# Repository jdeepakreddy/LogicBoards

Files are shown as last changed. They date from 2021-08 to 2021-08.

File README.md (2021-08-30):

## Full Documentation

I will amend this documentation as the project progresses.

**Logic Board 1 Variants:**

- Logic Board 1A (WiFi + BLE 5.0)
	- LB1A_DCA7M4_R512MB_F4GB (Dual Core A7 + M4, 512MB DDR3L RAM, 4GB eMMC)
	- LB1A_SCA7M4_R512MB_F4GB (Single Core A7 + M4, 512MB DDR3L RAM, 4GB eMMC)
- Logic Board 1B (Only WiFi)
	- LB1B_DCA7M4_R512MB_F4GB (Dual Core A7 + M4, 512MB DDR3L RAM, 4GB eMMC)
	- LB1B_SCA7M4_R512MB_F4GB (Single Core A7 + M4, 512MB DDR3L RAM, 4GB eMMC)
- Logic Board 1C (Only BLE 5.0)
	- LB1C_DCA7M4_R512MB_F4GB (Dual Core A7 + M4, 512MB DDR3L RAM, 4GB eMMC)
	- LB1C_SCA7M4_R512MB_F4GB (Single Core A7 + M4, 512MB DDR3L RAM, 4GB eMMC)
- Logic Board 1D (No wireless)
	- LB1D_DCA7M4_R512MB_F4GB (Dual Core A7 + M4, 512MB DDR3L RAM, 4GB eMMC)
	- LB1D_SCA7M4_R512MB_F4GB (Single Core A7 + M4, 512MB DDR3L RAM, 4GB eMMC)

**Logic Board I/O:**

Common expansion Board for all Logic Board 1 Variants. 

## A little background about the project

How it all started.

### Problem

While I was working on couple of popular linux dev boards like the BeagleBone Black and the Raspberry Pi, I've faced a few bunch of problems with both of them. Ofcourse, they are both fantastic boards to work with and they both have good community support, but, I are missing few things:

- **Raspberry Pi Compute Module 4 + IO Board**
    - CM4 is easy to use but not ideal for mass production.
    - No support for analog signals at hardware level.
    - Software PWM possible but not very precise.
    - Cannot support real time application or processing.
    - Not fully open-source and very minimum customization possible. <br>
<br>

- **BeagleBone Black**
    - Easy to use but user has to own build hardware for production.
    - PRUs make RT applications possible but super difficult to use.
    - Cannot support MIPI-DSI and HD graphics.
    - Programming PRUs is not an easy task.

### Solution

**Best of both worlds**

**Hello World STM32MP1 !!**

- Board design inspired from Raspberry Pi Compute Module 4 and CM4 IO board.
- Operating system derived from Beaglebone Black with implementation of Bonescript Library and Cloud9 IDE.
- Footprint compatible Single or dual Cortex-A7 Processors + dedicated Cortex-M4 core for real-time and low-power applications.
- Support for MIPI-DSI display for HMI applications.
- Fully open-source Hardware and Software.

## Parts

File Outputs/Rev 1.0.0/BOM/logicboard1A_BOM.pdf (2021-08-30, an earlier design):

Date | 28/07/2021
Rev. No. | 1.0.0
S/N | REF DESIGNATOR | MANUFACTURER PART NUMBER | VALUE | PACKAGE | QTY
1 | U8 | LBEE59B1LV-278 | - | | 1
2 | R49,R48,R47 | ERJ-1GN0R00C | 0E | 0201 | 3
3 | L8,L7 | LQP03TG1N5C02D | 1.5nH | 0201 | 2
4 | L6 | LQP03TG3N0C02D | 3.0nH | 0201 | 1
5 | L5 | LQP03TG1N0C02D | 1.0nH | 0201 | 1
6 | C86,C79,C32,C4,C40,C39,C38,C37,C36,C31,C30,C2 9,C28,C27,C26,C25,C24,C23,C20,C19,C18,C17,C16, C15,C14,C13,C12,C11,C10,C9,C8,C3 | 04026D104KAT2A | 100nF | 0402 | 32
7 | C85,C62,C61,C60,C59,C58,C57,C56,C55,C53 | GRM155R61A475MEAAD | 4.7uF | 0402 | 10
8 | C78 | GRT0335C1H2R0CA02D | 2.0pF | 0201 | 1
9 | C71,C33 | GRT0335C1ER30WA02D | 0.3pF | 0201 | 2
10 | U1 | STM32MP157CAC3 | - | | 1
11 | U2 | AS4C256M16D3LC-12BCN | - | | 1
12 | R6,R46,R35,R27 | RC0402JR-1010KL | 10k | 0402 | 4
13 | U7,U6,U5 | DF40C-70DP-0.4V(51) | - | | 3
14 | C76,C77,C75 | 04026A100KAT2A | 10pF | 0402 | 3
15 | C74,C73,C72,C70,C69,C68,C67,C66,C65,C64,C63,C 52,C51,C6,C5,C2,C1 | JMK105BJ105KV-F | 1uF | 0402 | 17
16 | X2 | TSX-3225 24.0000MF10Z-C3 | 24MHz | | 1
17 | X1 | SIT1533AC-H5-DCC-32.768E | 32.768kHz | | 1
18 | U4 | STPMIC1BPQR | - | | 1
19 | U3 | S40FC004C1B2C00000 | - | | 1
20 | R45,R44,R43,R42,R41,R40,R39,R38,R37,R36 | RC0402FR-0747KL | 47k | 0402 | 10
21 | R34,R1 | RC0402JR-07240RL | 240E | 0402 | 2
22 | R33,R32,R31,R30,R29,R28,R25,R24,R23,R22,R21,R 20,R19,R18,R17,R16,R15,R14,R13,R12,R11,R10,R9, R8 | RC0402JR-0756RL | 56E | 0402 | 24
23 | R26 | RC0402JR-7D100RL | 100E | 0402 | 1
24 | R7 | RC0402FR-073KL | 3k | 0402 | 1
25 | R5,R4,R3,R2 | RC0402FR-7D1K5L | 1k5 | 0402 | 4

LOGIC BOARD 1A BILL OF MATERIALS www.logicboards.org

26 | L4,L3,L2,L1 | MGV2520101R0M-10 | 1uH | 0402 | 4
27 | C54,C46,C45,C44,C43,C41,C35,C34,C22,C21 | GRM155R60J106ME15D | 10uF | 0402 | 10
28 | C50,C49,C48,C47 | C3216X5R1V226M160AC | 22uF | 1206 | 4
29 | C42 | LMK105ABJ225KVHF | 2.2uF | 0402 | 1
30 | C7 | GRM155R71H103KA88D | 10nF | 0402 | 1

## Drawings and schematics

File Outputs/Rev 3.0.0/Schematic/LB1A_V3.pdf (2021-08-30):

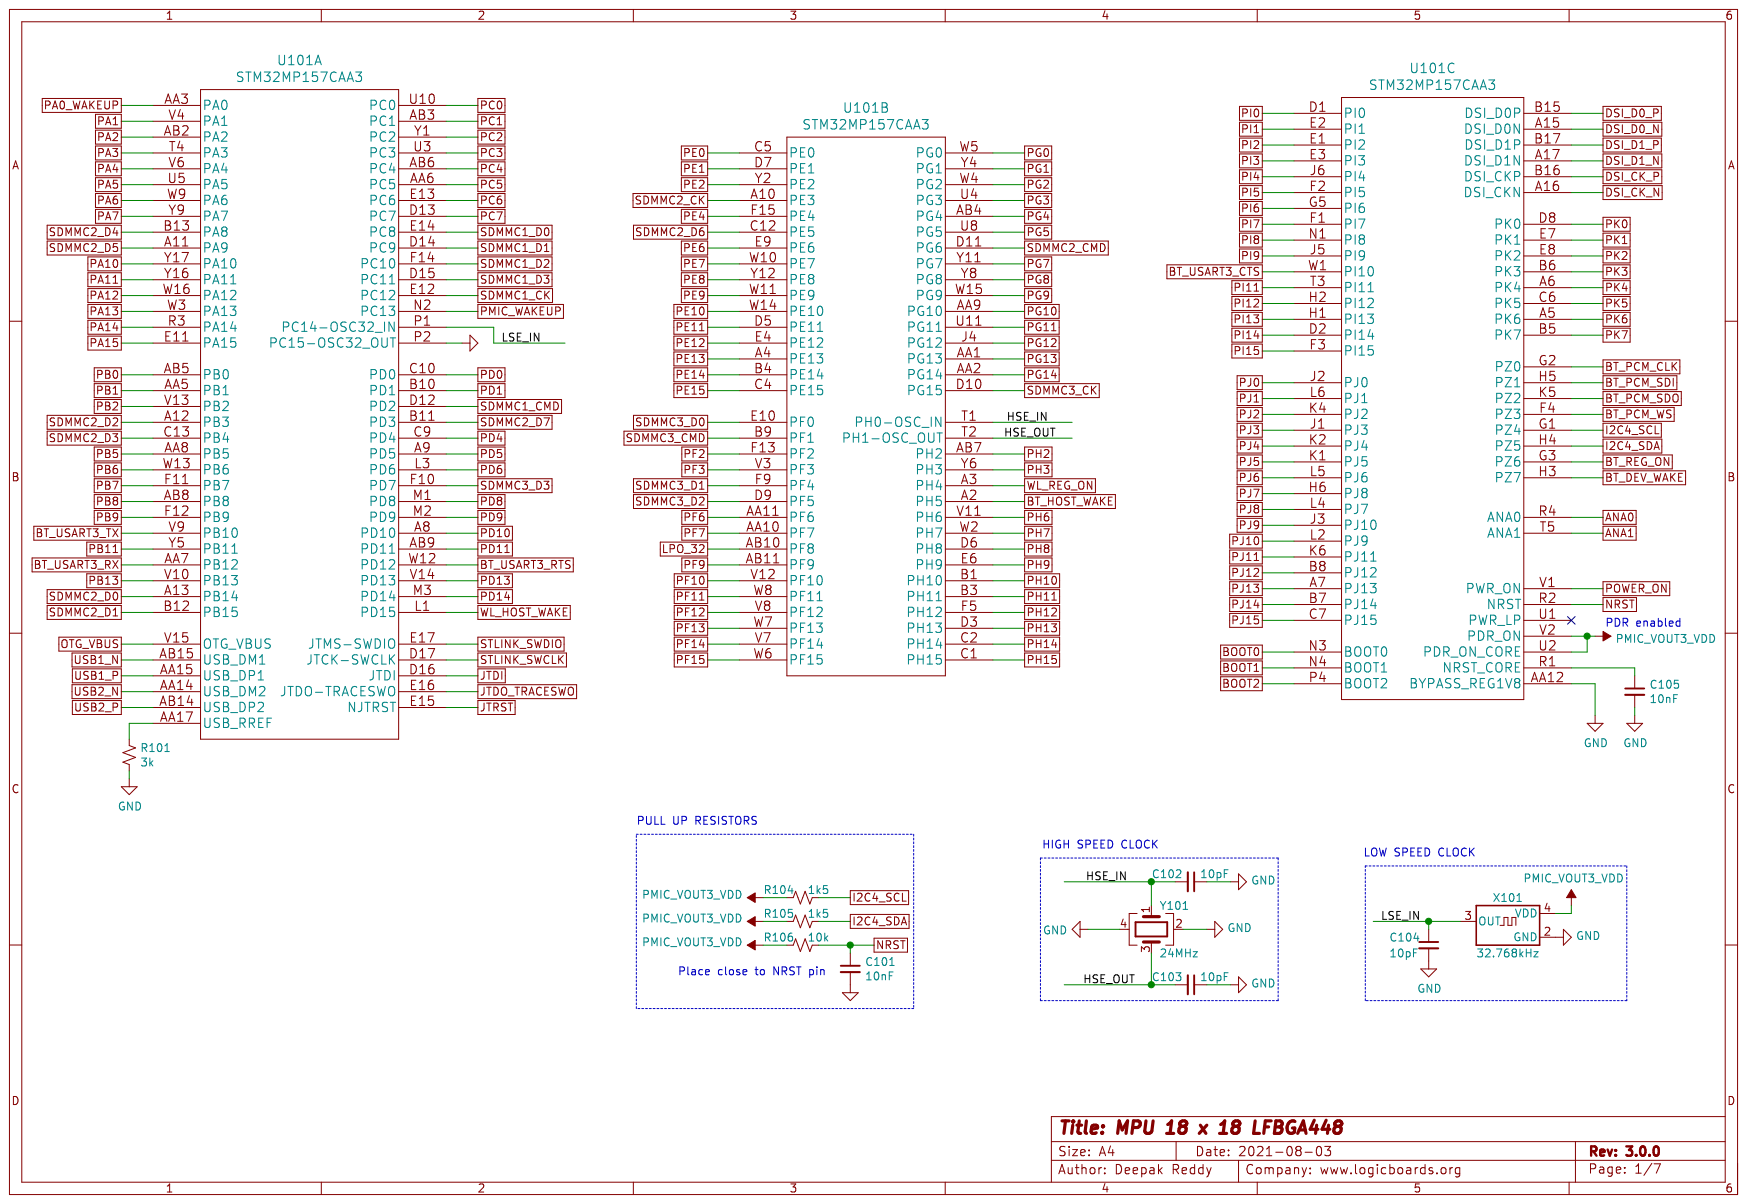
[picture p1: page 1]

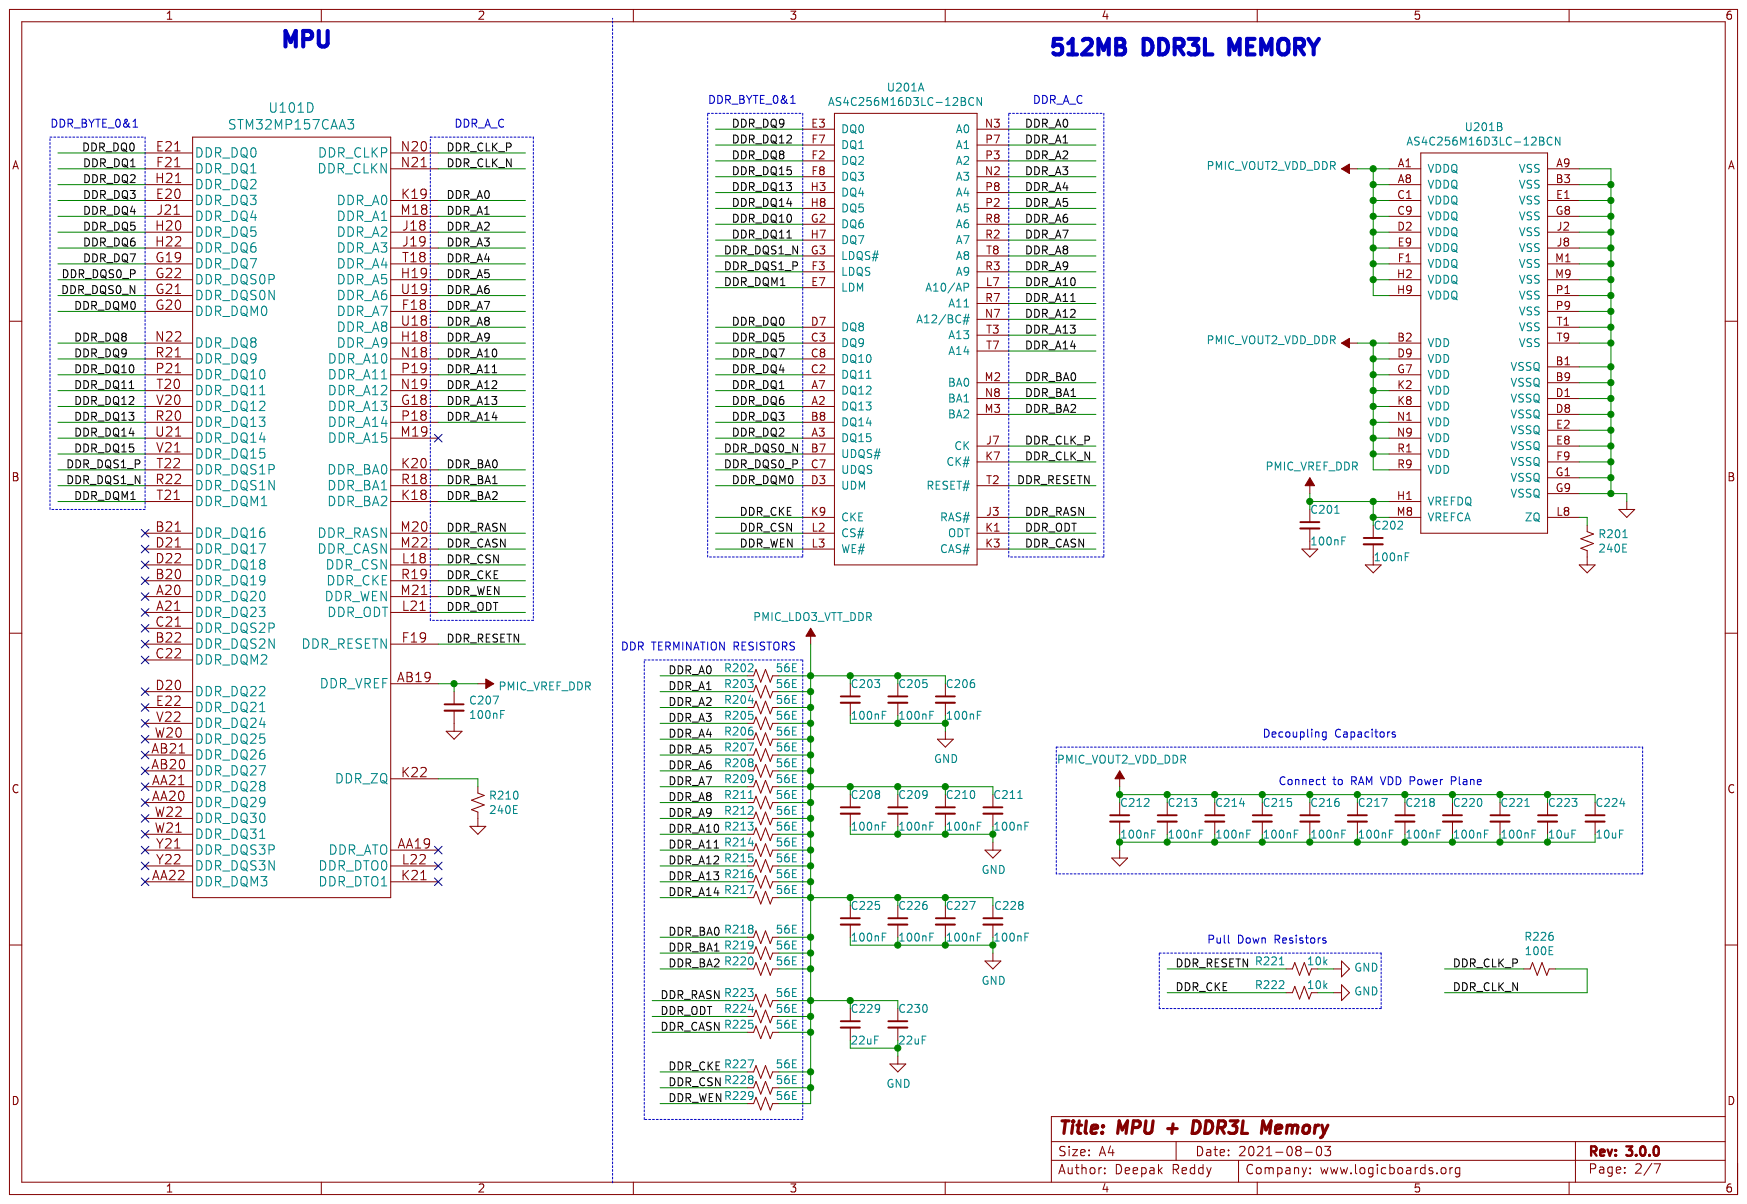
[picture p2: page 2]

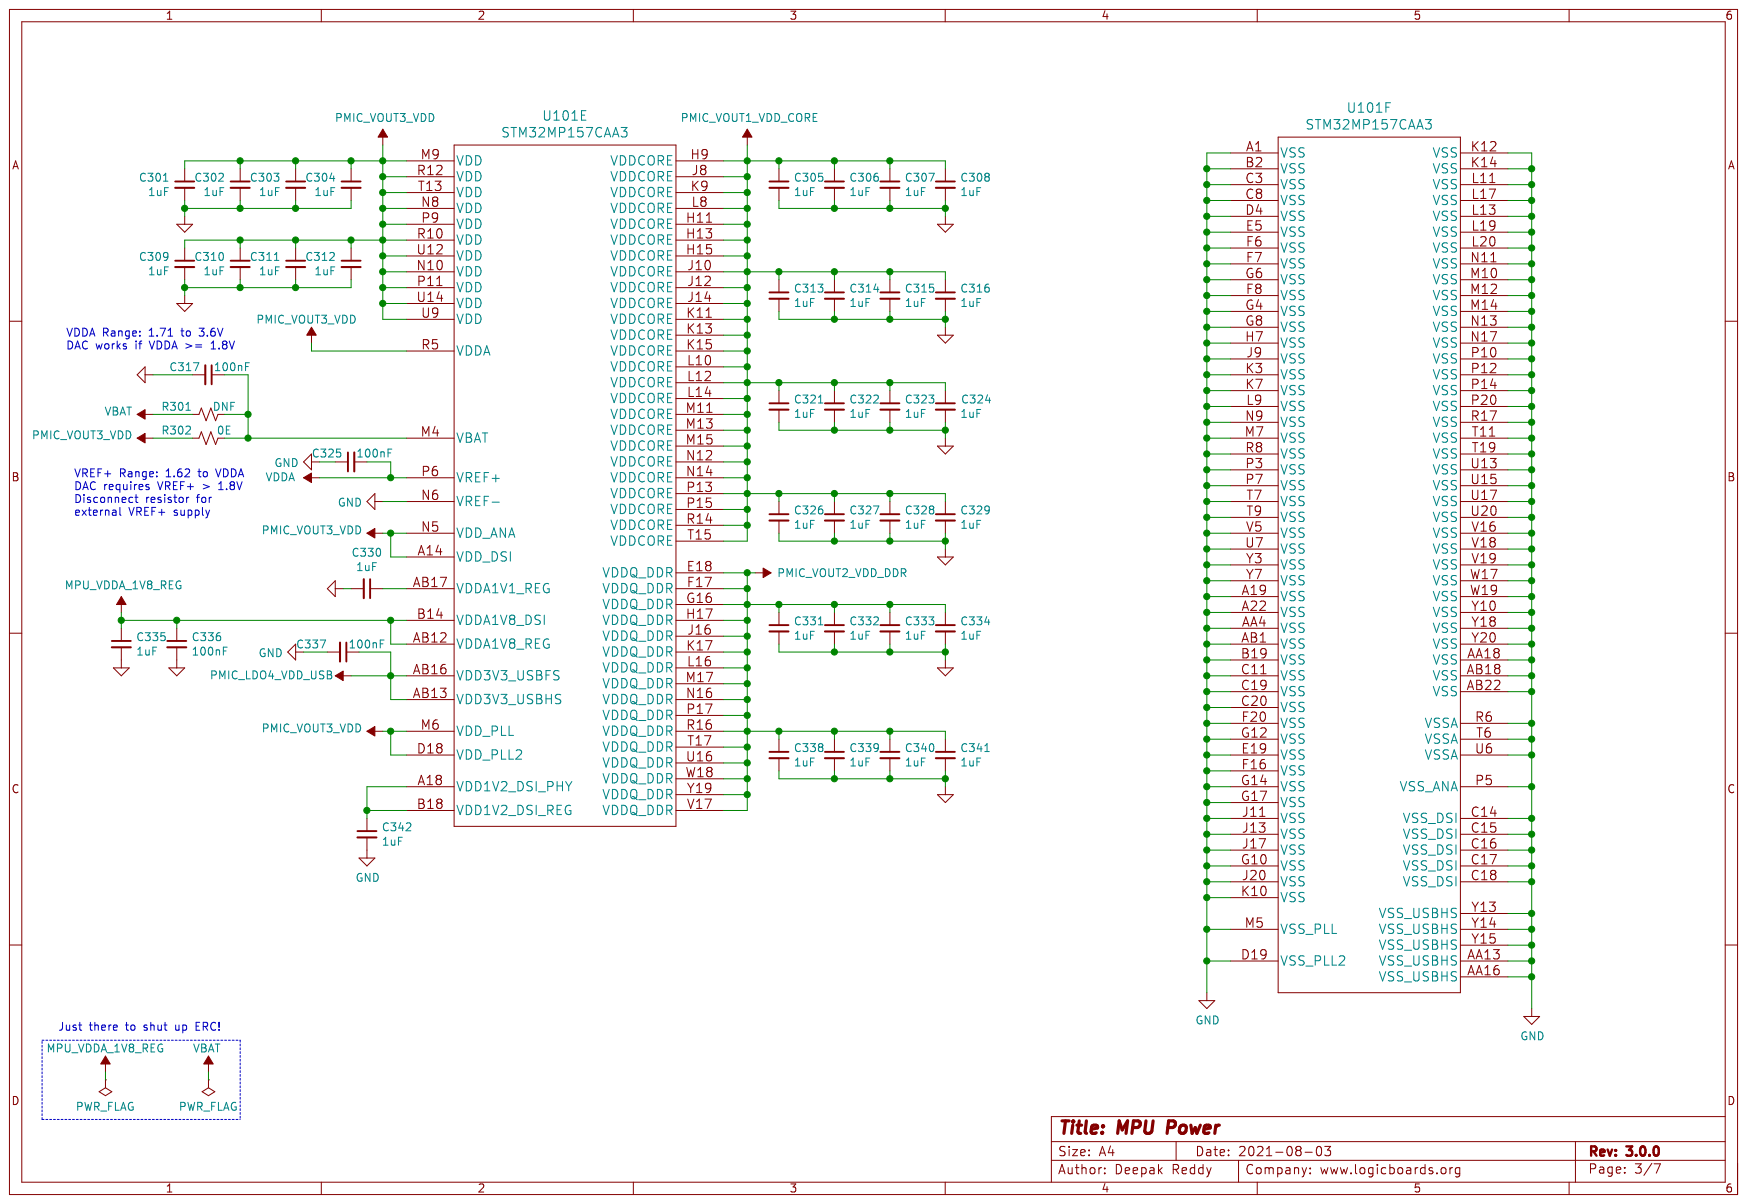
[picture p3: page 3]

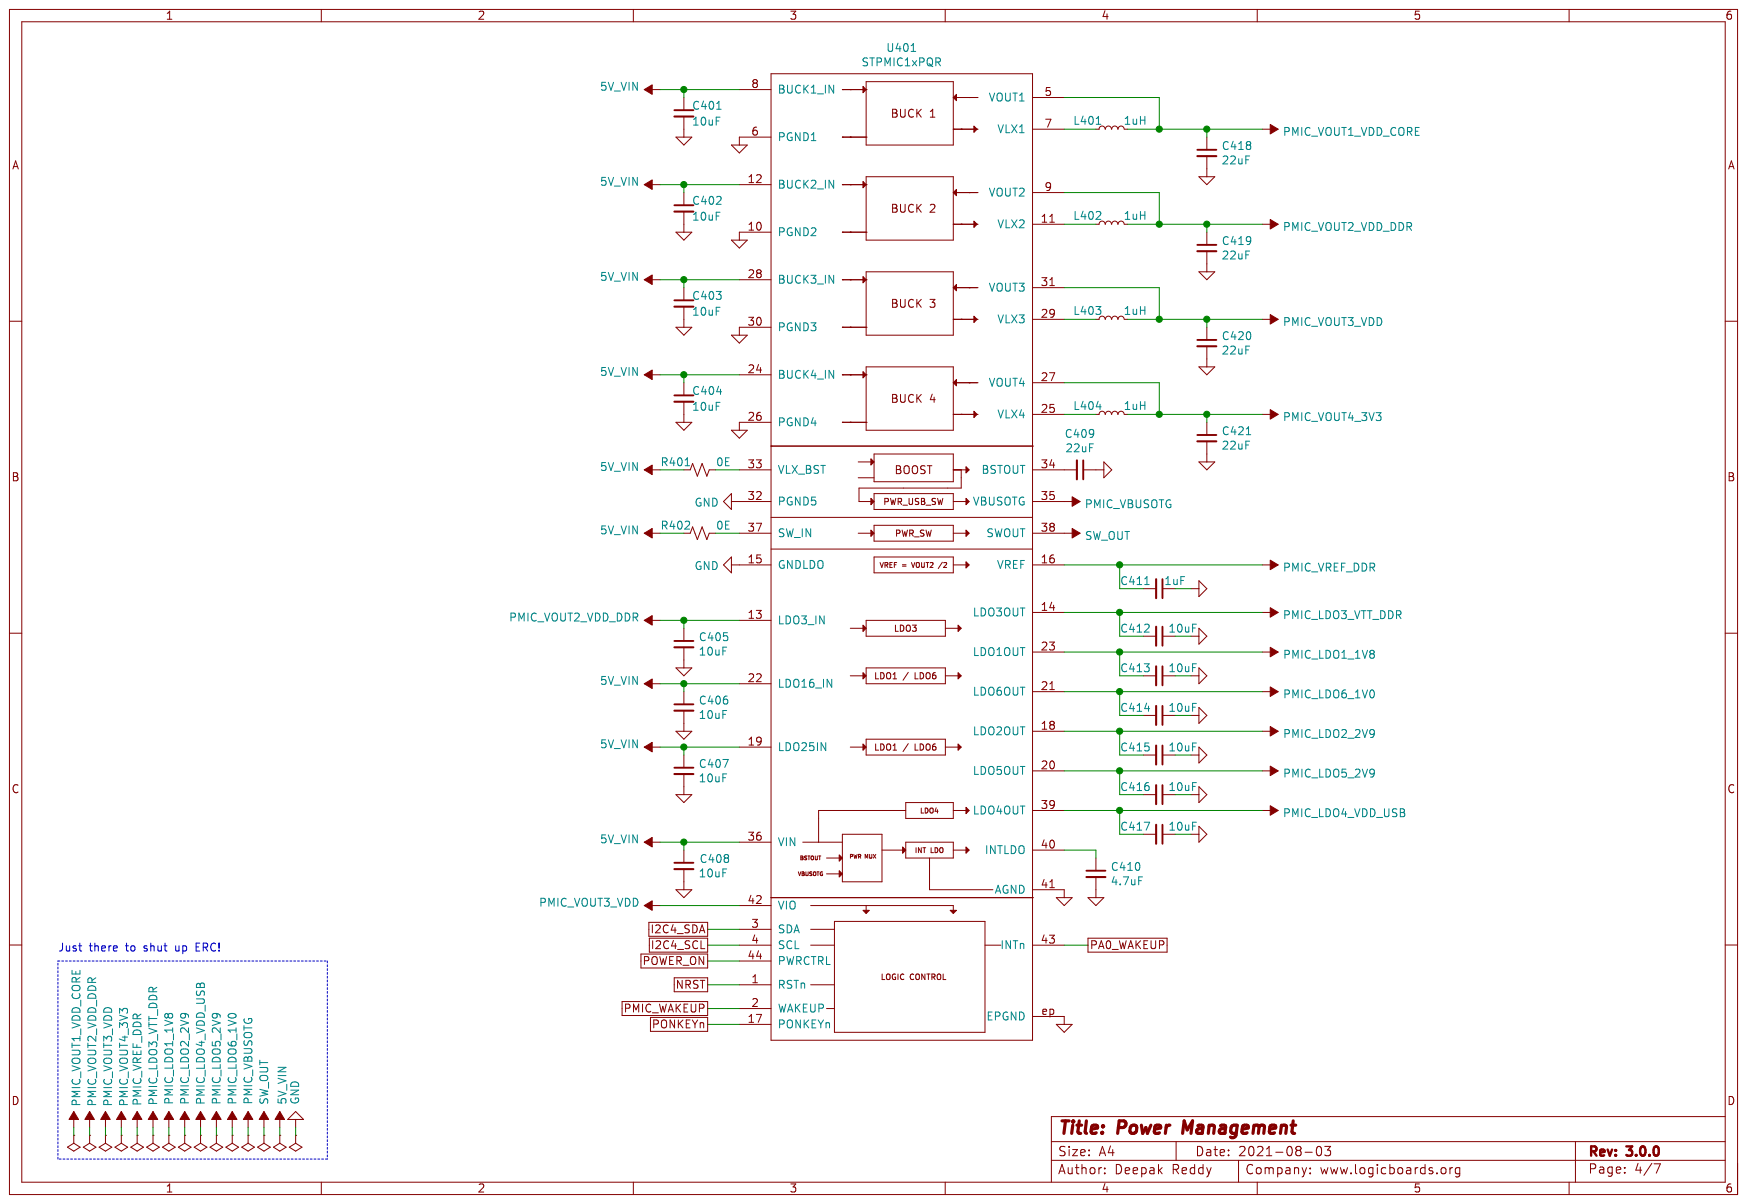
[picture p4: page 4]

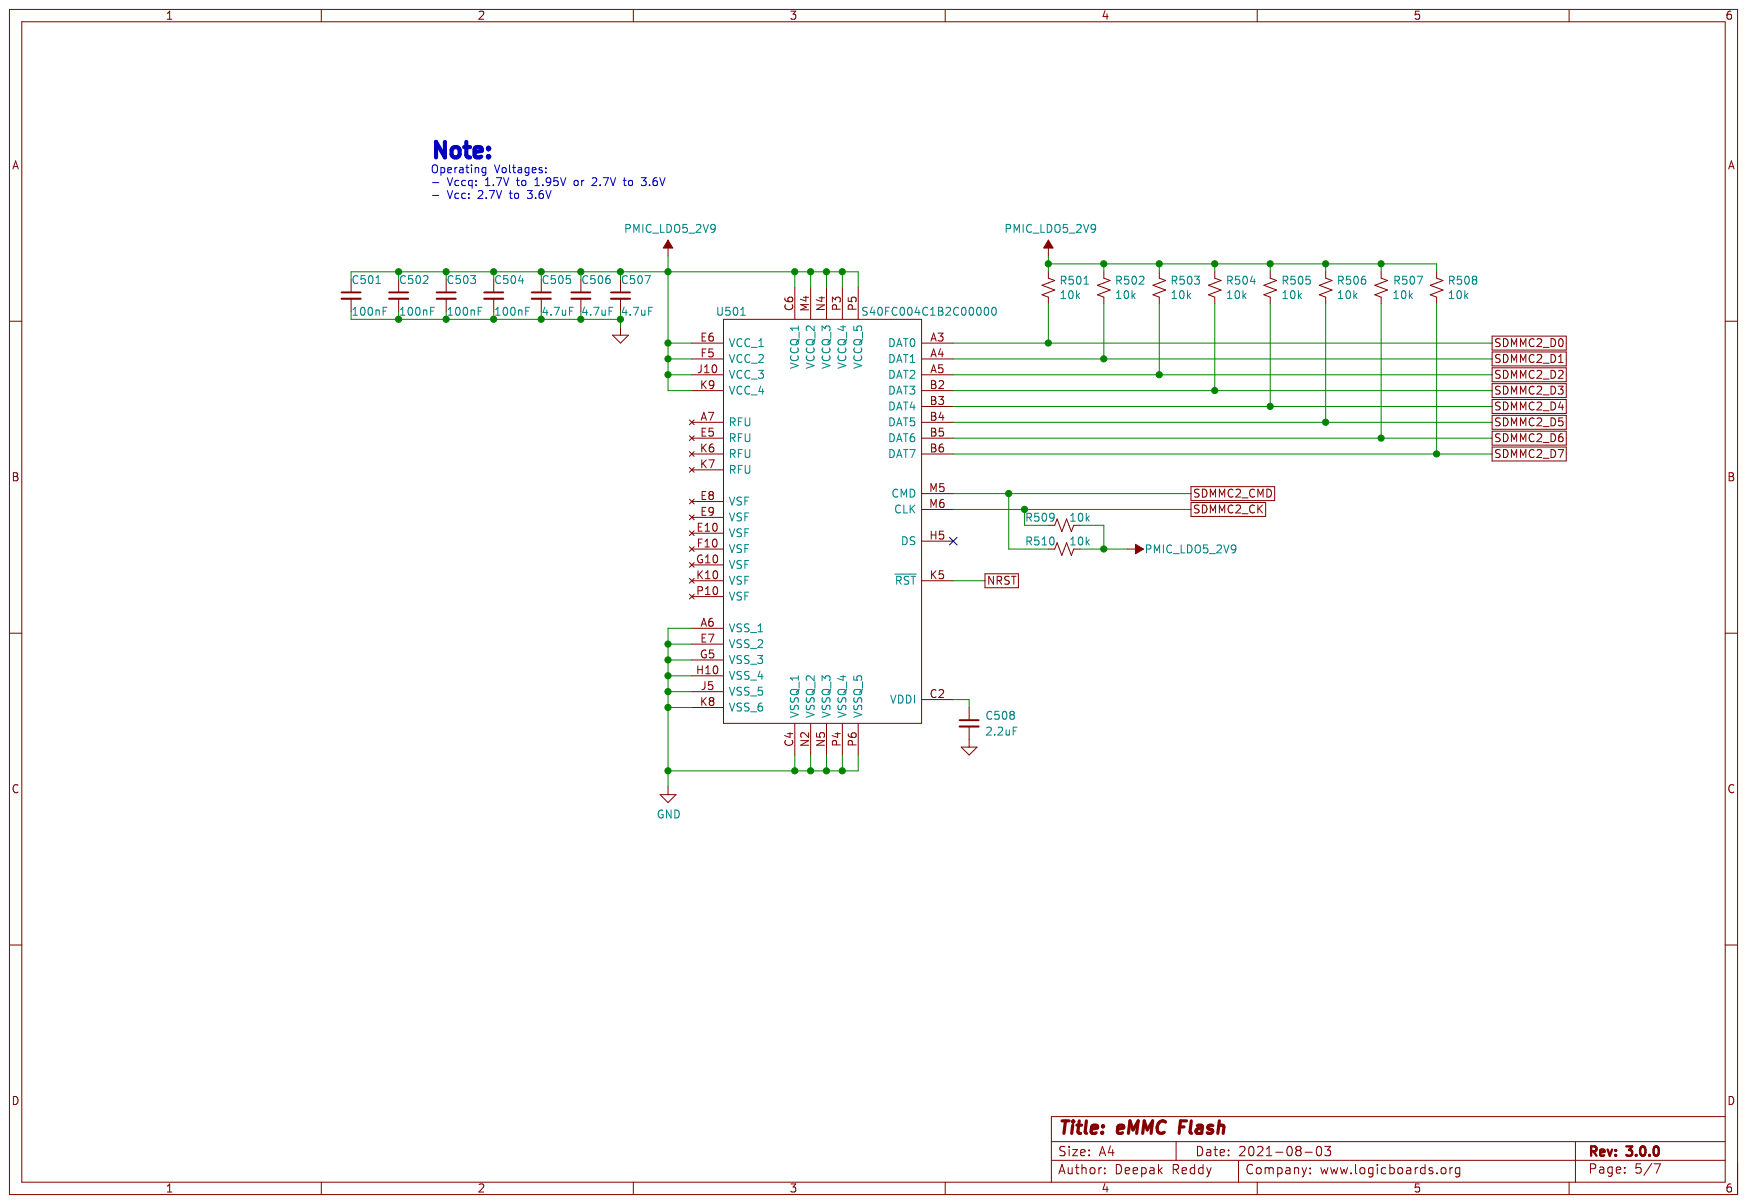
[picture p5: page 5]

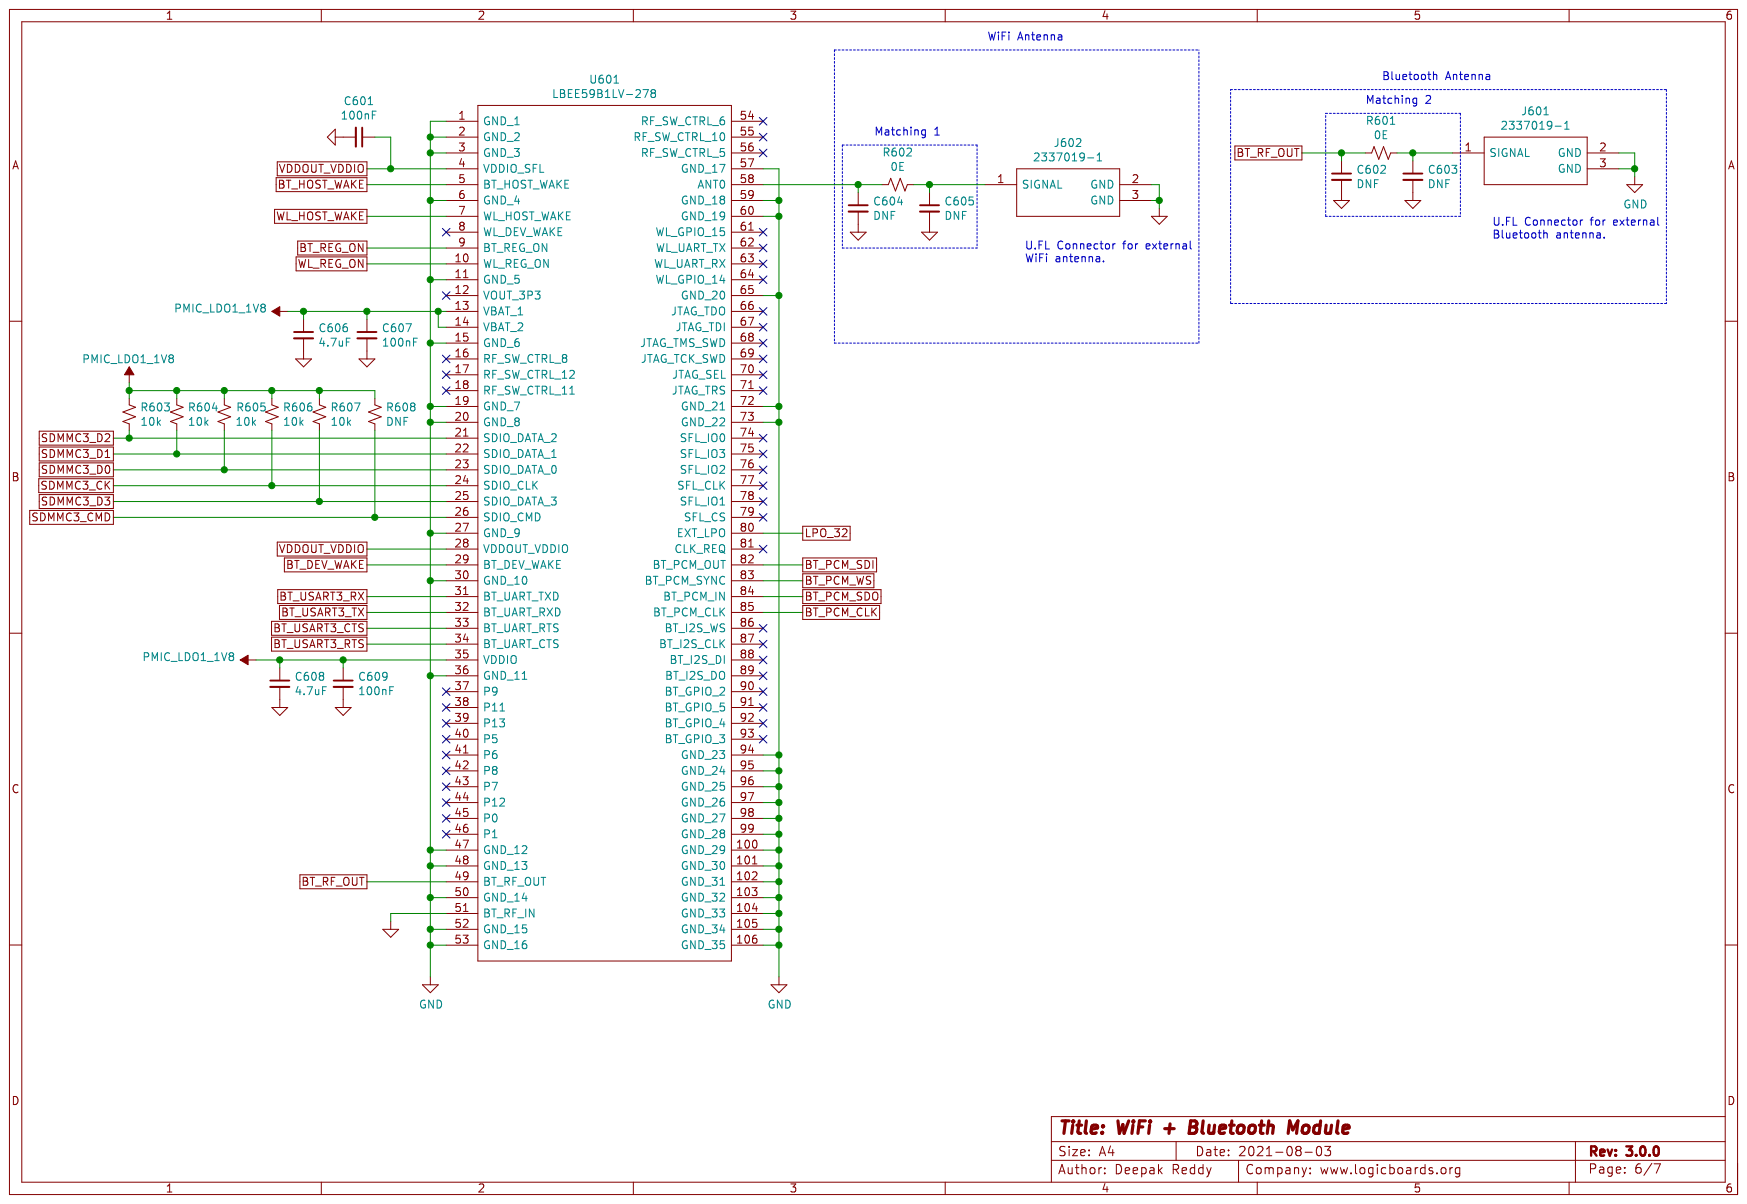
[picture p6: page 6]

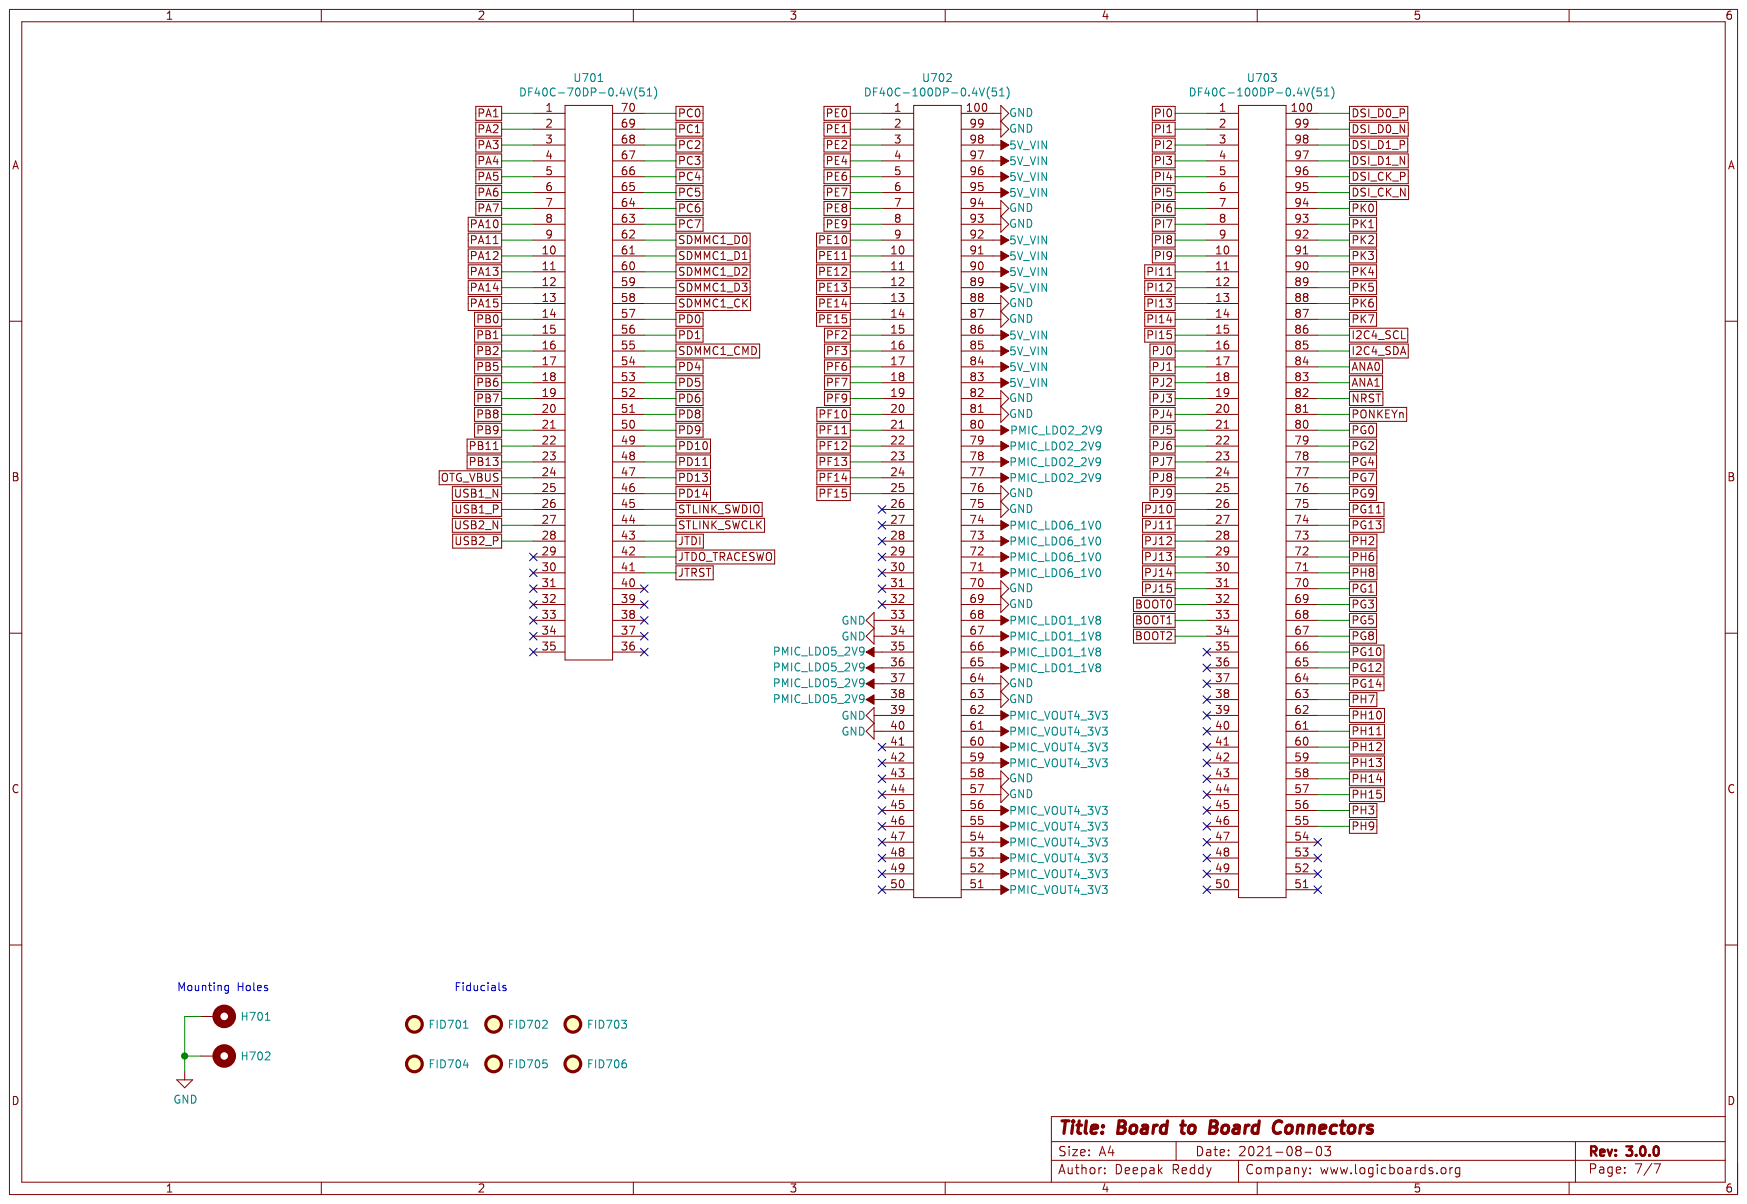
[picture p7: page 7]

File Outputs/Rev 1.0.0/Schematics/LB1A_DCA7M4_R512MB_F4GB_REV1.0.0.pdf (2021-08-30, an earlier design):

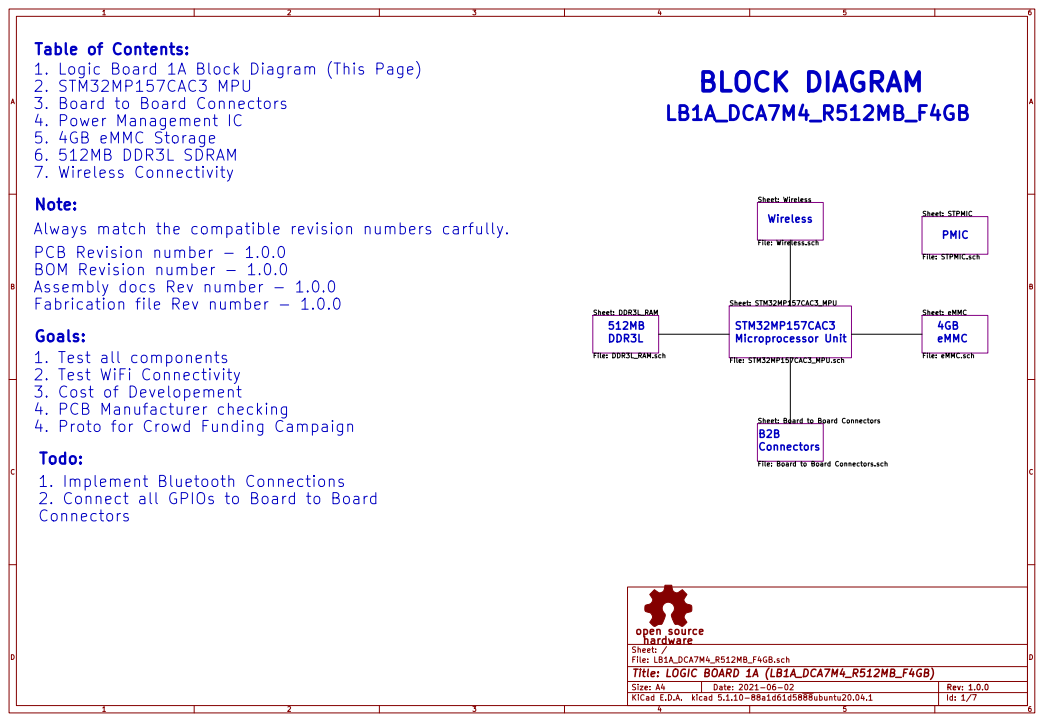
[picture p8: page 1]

Table of Contents:
1. Logic Board 1A Block Diagram (This Page)
2. STM32MP157CAC3 MPU
3. Board to Board Connectors
4. Power Management IC
5. 4GB eMMC Storage
6. 512MB DDR3L SDRAM
7. Wireless Connectivity
Note:
Always match the compatible revision numbers carfully.
PCB Revision number - 1.0.0
BOM Revision number - 1.0.0
Assembly docs Rev number - 1.0.0
Fabrication file Rev number - 1.0.0
Goals:
1. Test all components
2. Test WiFi Connectivity
3. Cost of Developement
4. PCB Manufacturer checking
4. Proto for Crowd Funding Campaign
Todo:
1. Implement Bluetooth Connections
2. Connect all GPIOs to Board to Board
Connectors

BLOCK DIAGRAM
LB1A_DCA7M4_R512MB_F4GB
Sheet: Wireless File: Wireless.sch Sheet: Board to Board Connectors File: Board to Board Connectors.sch Sheet: STM32MP157CAC3_MPU
File: DDR3L_RAM.sch hardware open source

File: STPMIC.sch Sheet: eMMC

File: LB1A_DCA7M4_R512MB_F4GB.sch Sheet: /
Id: 1/7 Title: LOGIC BOARD 1A (LB1A_DCA7M4_R512MB_F4GB)

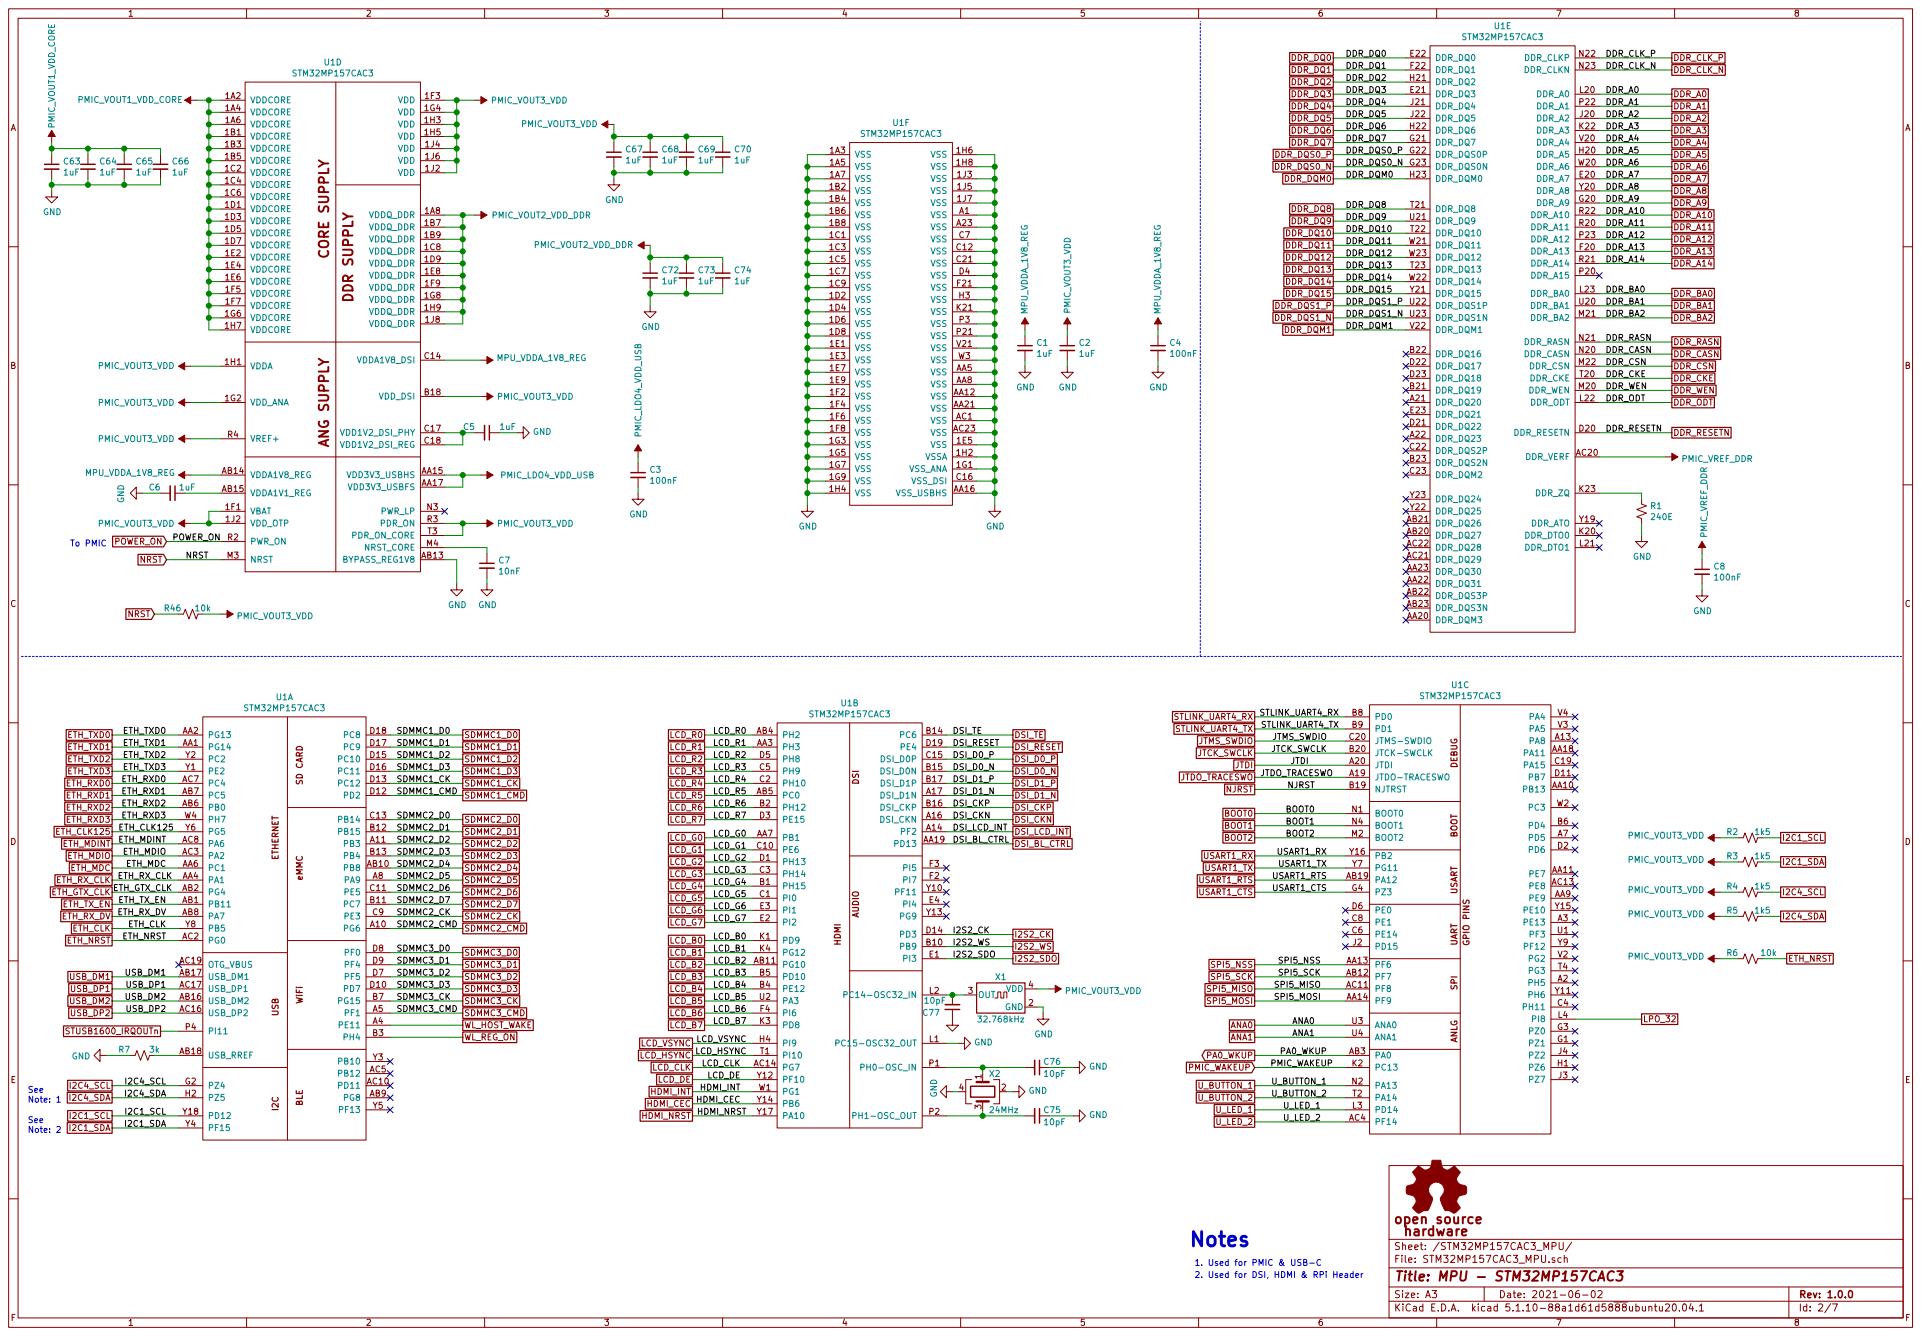
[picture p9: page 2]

1. Used for PMIC & USB-C
2. Used for DSI, HDMI & RPi Header

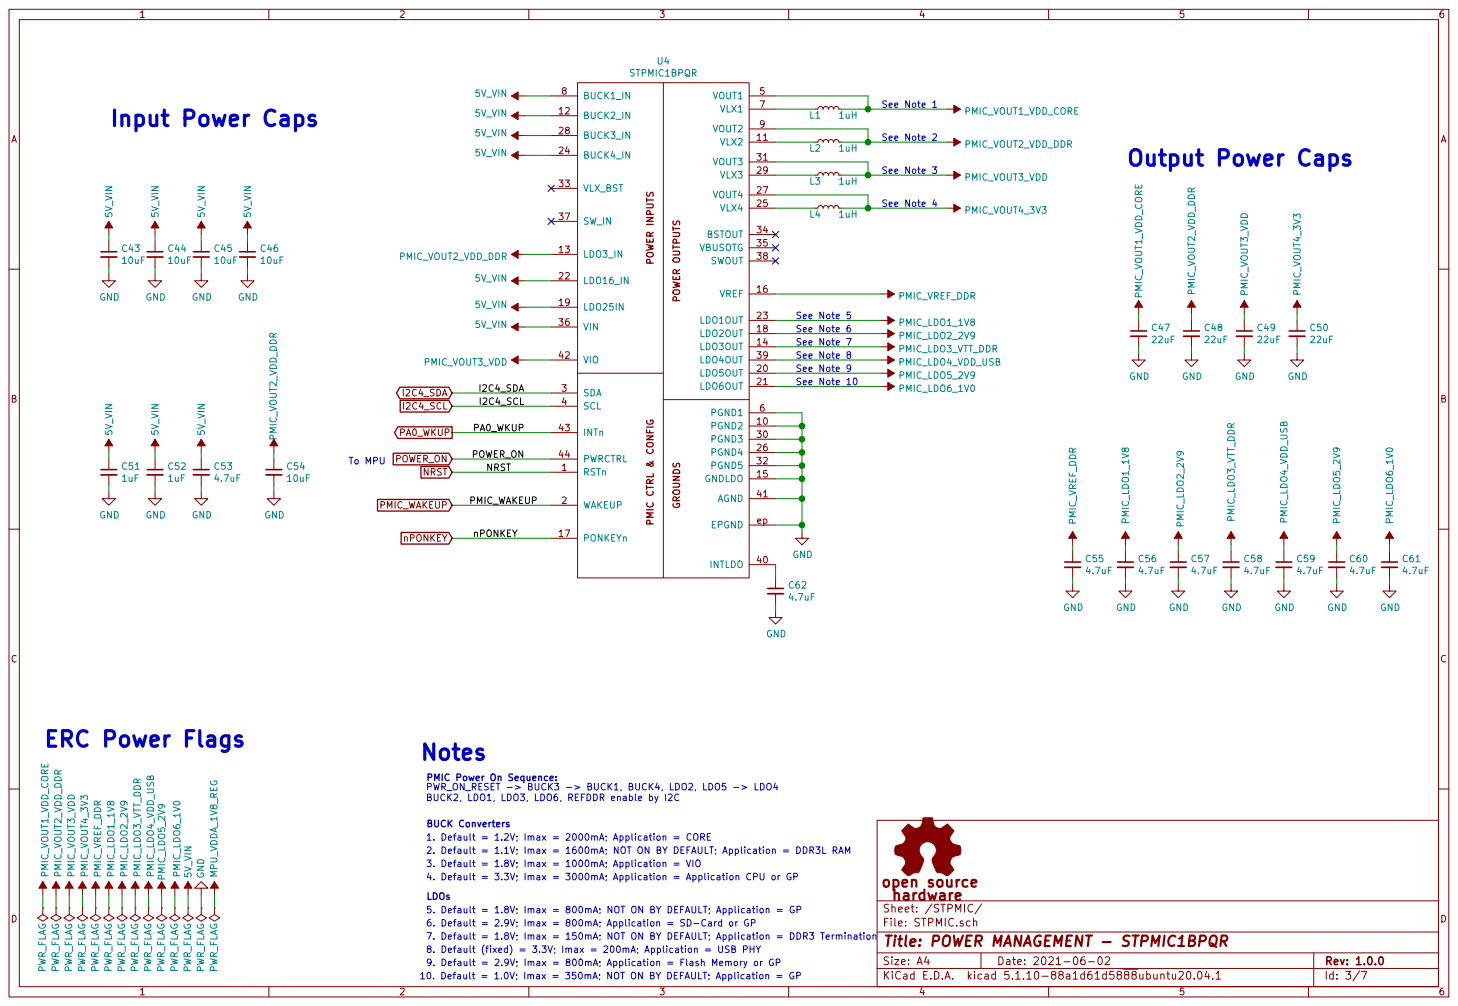
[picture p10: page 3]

PMIC Power On Sequence:
LDOs BUCK Converters PWR_ON_RESET -> BUCK3 -> BUCK1, BUCK4, LDO2, LDO5 -> LDO4 BUCK2, LDO1, LDO3, LDO6, REFDDR enable by I2C

1. Default = 1.2V; Imax = 2000mA; Application = CORE
2. Default = 1.1V; Imax = 1600mA; NOT ON BY DEFAULT; Application = DDR3L RAM
3. Default = 1.8V; Imax = 1000mA; Application = VIO
4. Default = 3.3V; Imax = 3000mA; Application = Application CPU or GP

5. Default = 1.8V; Imax = 800mA; NOT ON BY DEFAULT; Application = GP
6. Default = 2.9V; Imax = 800mA; Application = SD-Card or GP
7. Default = 1.8V; Imax = 150mA; NOT ON BY DEFAULT; Application = DDR3 Termination
8. Default (fixed) = 3.3V; Imax = 200mA; Application = USB PHY
9. Default = 2.9V; Imax = 800mA; Application = Flash Memory or GP
10. Default = 1.0V; Imax = 350mA; NOT ON BY DEFAULT; Application = GP

Id: 3/7 Title: POWER MANAGEMENT - STPMIC1BPQR

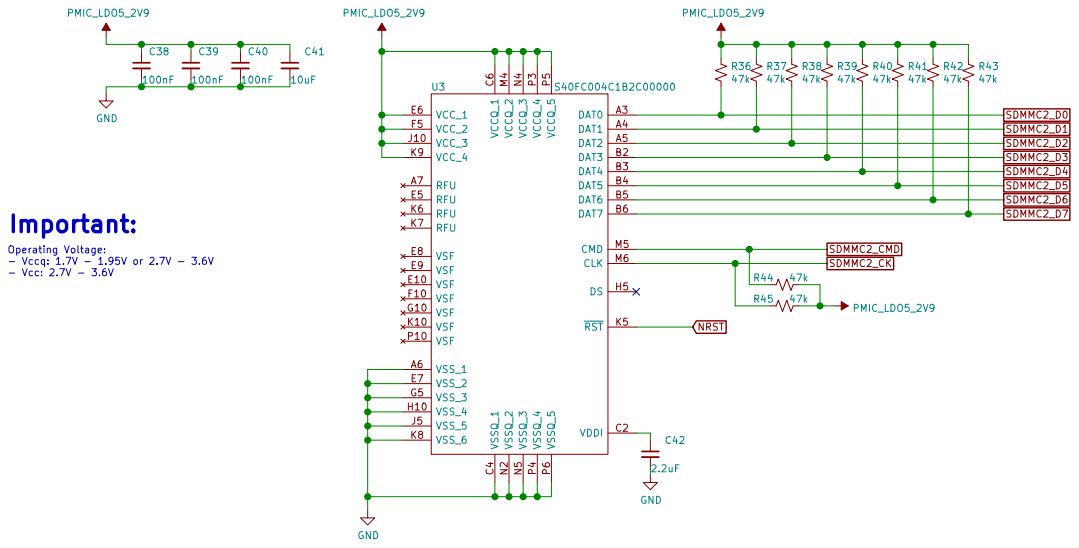
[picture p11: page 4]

File: eMMC.sch Sheet: /eMMC/
Id: 4/7 Title: eMMC FLASH - S40FC004C1B2C00000

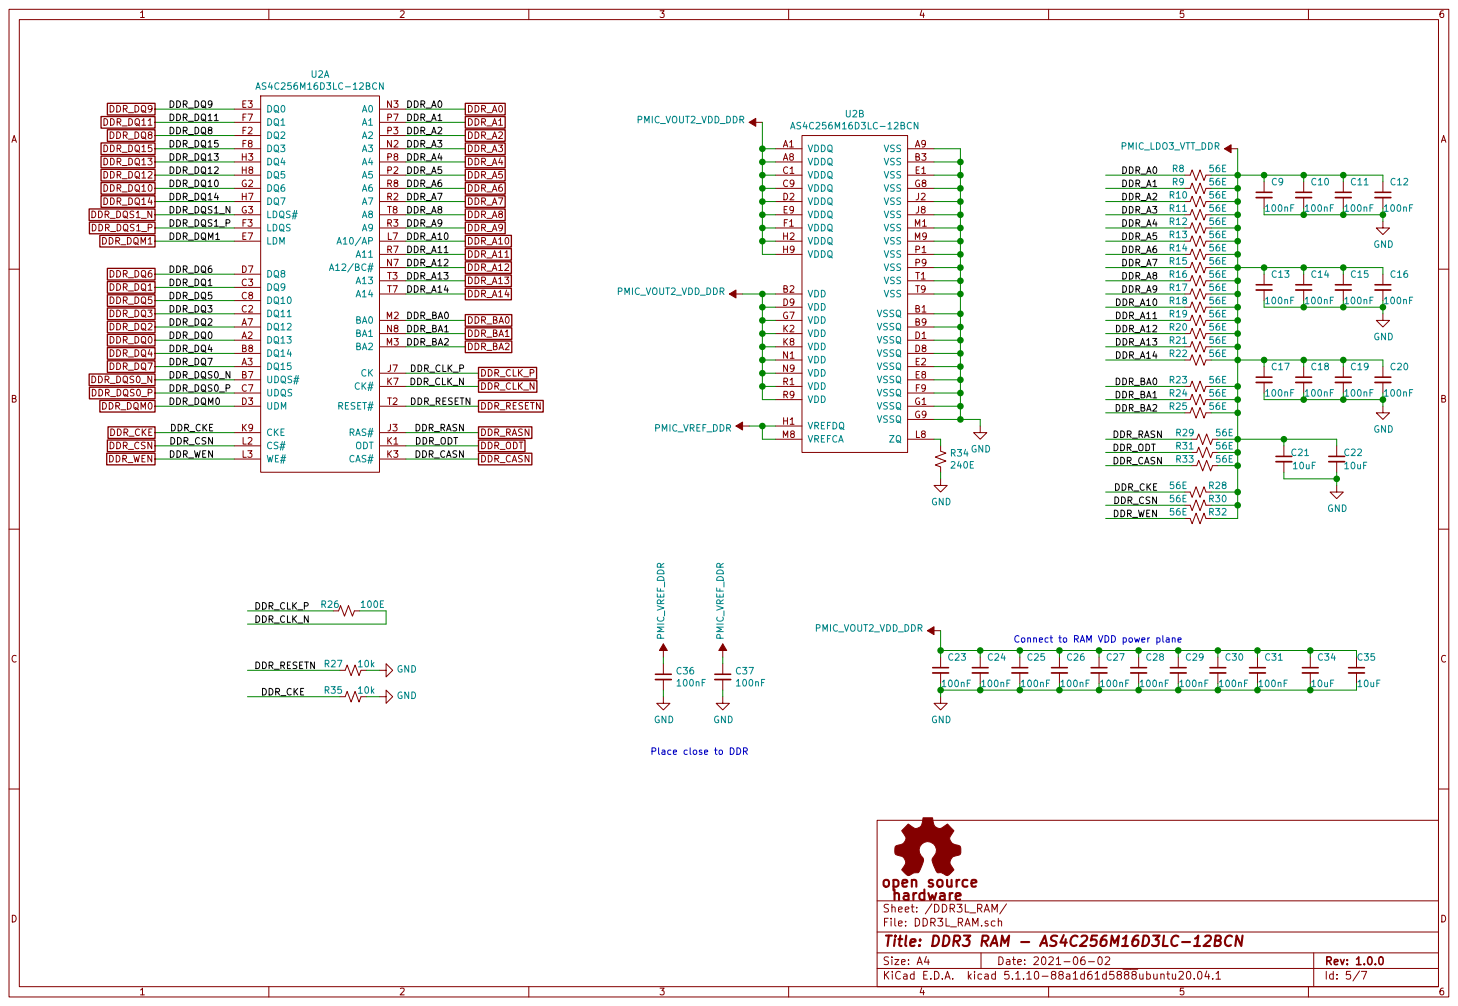
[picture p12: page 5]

Connect to RAM VDD power plane


File: Wireless.sch Sheet: /Wireless/
Id: 6/7 Title: WIFI + BLUETOOTH - LBEE59B1LV-278


Id: 7/7 Title: BOARD TO BOARD CONNECTORS - DF40C-70DP-0.4V(51) File: Board to Board Connectors.sch Sheet: /Board to Board Connectors/ FID6

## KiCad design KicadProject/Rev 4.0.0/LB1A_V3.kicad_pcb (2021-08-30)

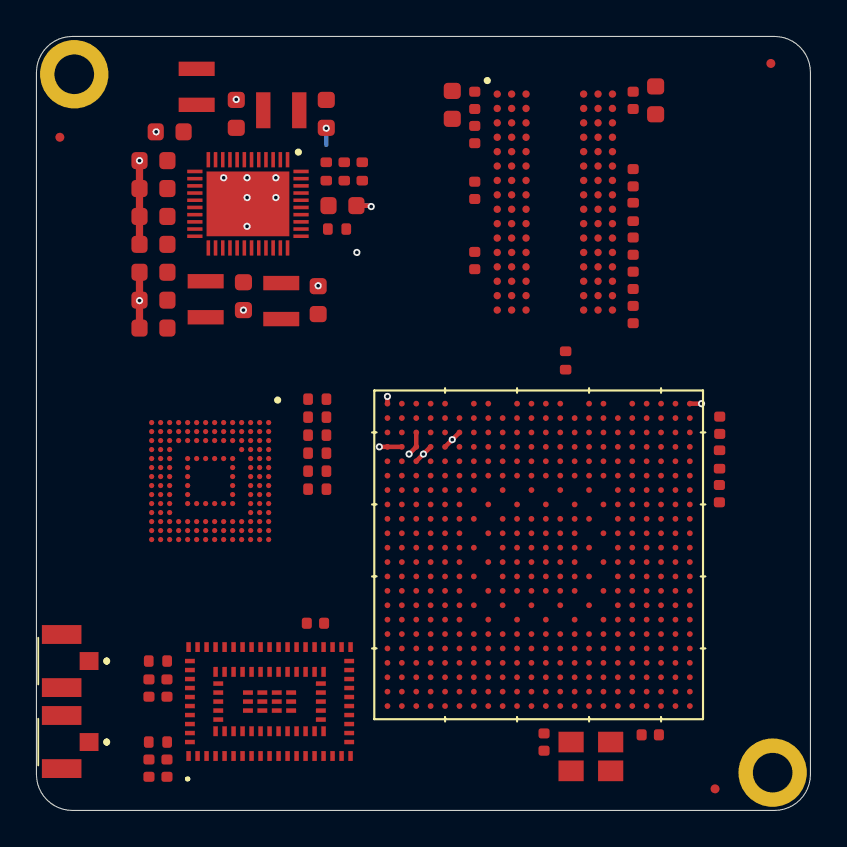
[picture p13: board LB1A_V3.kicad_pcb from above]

Board: 6 copper layers, 43.0 x 43.0 mm, 187 parts (0 on the bottom side), 284 nets.

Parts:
C101, C105: 10nF; C_0402_1005Metric
C102, C103, C104: 10pF; C_0402_1005Metric
C201, C202, C203, C205, C206, C207, C208, C209, C210, C211, C212, C213, C214, C215, C216, C217, C218, C220, C221, C225, C226, C227, C228, C317, C325, C336, C337, C501, C502, C503, C504, C601, C607, C609: 100nF; C_0402_1005Metric
C223, C224, C401, C402, C403, C404, C405, C406, C407, C408, C412, C413, C414, C415, C416, C417: 10uF; C_0603_1608Metric
C229, C230, C409, C418, C419, C420, C421: 22uF; C_0603_1608Metric
C301, C302, C303, C304, C305, C306, C307, C308, C309, C310, C311, C312, C313, C314, C315, C316, C321, C322, C323, C324, C326, C327, C328, C329, C330, C331, C332, C333, C334, C335, C338, C339, C340, C342: 1uF; C_0402_1005Metric
C410, C505, C506, C507, C606, C608: 4.7uF; C_0402_1005Metric
C411: 1uF; C_0603_1608Metric
C508: 2.2uF; C_0402_1005Metric
C602, C603, C604, C605: DNF; C_0402_1005Metric
FID701, FID702, FID703, FID704, FID705, FID706: Fiducial; Fiducial_0.5mm_Mask1.5mm
H701, H702: MountingHole_Pad; MountingHole_2.2mm_M2_DIN965_Pad
J601, J602: 2337019-1; 23370191
L401, L402, L403, L404: 1uH; MGV2520101R0M-10
R101: 3k; R_0402_1005Metric
R104, R105: 1k5; R_0402_1005Metric
R106, R221, R222, R501, R502, R503, R504, R505, R506, R507, R508, R509, R510, R603, R604, R605, R606, R607: 10k; R_0402_1005Metric
R201, R210: 240E; R_0402_1005Metric
R202, R203, R204, R205, R206, R207, R208, R209, R211, R212, R213, R214, R215, R216, R217, R218, R219, R220, R223, R224, R225, R227, R228, R229: 56E; R_0402_1005Metric
R226: 100E; R_0402_1005Metric
R301, R608: DNF; R_0402_1005Metric
R302, R401, R402, R601, R602: 0E; R_0402_1005Metric
U101: STM32MP157CAA3
U201: AS4C256M16D3LC-12BCN
U401: STPMIC1xPQR; STPMIC1BPQR
U501: S40FC004C1B2C00000
U601: LBEE59B1LV-278; LBEE59B1LV278
U701: DF40C-70DP-0.4V(51); DF40C70DP04V51
U702, U703: DF40C-100DP-0.4V(51); DF40C100DP04V51
X101: 32.768kHz; SiT1533AC-H5-DCC-32.768E
Y101: 24MHz; TSX3225240000MF10ZC3

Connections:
5V_VIN: C401.1, C402.1, C403.1, C404.1, C406.1, C407.1, C408.1, R401.2, R402.2, U401.8, U401.12, U401.19, U401.22, U401.24, U401.28, U401.36, U702.83, U702.84, U702.85, U702.86, U702.89, U702.90, U702.91, U702.92, U702.95, U702.96, U702.97, U702.98
/HSE_IN: C102.2, U101.T1, Y101.1
/HSE_OUT: C103.2, U101.T2, Y101.3
/LSE_IN: C104.1, U101.P1, X101.3
/MPU_DDR3L_Memory/DDR_A0: R202.2, U101.K19, U201.N3
/MPU_DDR3L_Memory/DDR_A1: R203.2, U101.M18, U201.P7
/MPU_DDR3L_Memory/DDR_A2: R204.2, U101.J18, U201.P3
/MPU_DDR3L_Memory/DDR_A3: R205.2, U101.J19, U201.N2
/MPU_DDR3L_Memory/DDR_A4: R206.2, U101.T18, U201.P8
/MPU_DDR3L_Memory/DDR_A5: R207.2, U101.H19, U201.P2
/MPU_DDR3L_Memory/DDR_A6: R208.2, U101.U19, U201.R8
/MPU_DDR3L_Memory/DDR_A7: R209.2, U101.F18, U201.R2
/MPU_DDR3L_Memory/DDR_A8: R211.2, U101.U18, U201.T8
/MPU_DDR3L_Memory/DDR_A9: R212.2, U101.H18, U201.R3
/MPU_DDR3L_Memory/DDR_A10: R213.2, U101.N18, U201.L7
/MPU_DDR3L_Memory/DDR_A11: R214.2, U101.P19, U201.R7
/MPU_DDR3L_Memory/DDR_A12: R215.2, U101.N19, U201.N7
/MPU_DDR3L_Memory/DDR_A13: R216.2, U101.G18, U201.T3
/MPU_DDR3L_Memory/DDR_A14: R217.2, U101.P18, U201.T7
/MPU_DDR3L_Memory/DDR_BA0: R218.2, U101.K20, U201.M2
/MPU_DDR3L_Memory/DDR_BA1: R219.2, U101.R18, U201.N8
/MPU_DDR3L_Memory/DDR_BA2: R220.2, U101.K18, U201.M3
/MPU_DDR3L_Memory/DDR_CASN: R225.2, U101.M22, U201.K3
/MPU_DDR3L_Memory/DDR_CKE: R222.2, R227.2, U101.R19, U201.K9
/MPU_DDR3L_Memory/DDR_CLK_N: R226.1, U101.N21, U201.K7
/MPU_DDR3L_Memory/DDR_CLK_P: R226.2, U101.N20, U201.J7
/MPU_DDR3L_Memory/DDR_CSN: R228.2, U101.L18, U201.L2
/MPU_DDR3L_Memory/DDR_DQ0: U101.E21, U201.D7
/MPU_DDR3L_Memory/DDR_DQ1: U101.F21, U201.A7
/MPU_DDR3L_Memory/DDR_DQ2: U101.H21, U201.A3
/MPU_DDR3L_Memory/DDR_DQ3: U101.E20, U201.B8
/MPU_DDR3L_Memory/DDR_DQ4: U101.J21, U201.C2
/MPU_DDR3L_Memory/DDR_DQ5: U101.H20, U201.C3
/MPU_DDR3L_Memory/DDR_DQ6: U101.H22, U201.A2
/MPU_DDR3L_Memory/DDR_DQ7: U101.G19, U201.C8
/MPU_DDR3L_Memory/DDR_DQ8: U101.N22, U201.F2
/MPU_DDR3L_Memory/DDR_DQ9: U101.R21, U201.E3
/MPU_DDR3L_Memory/DDR_DQ10: U101.P21, U201.G2
/MPU_DDR3L_Memory/DDR_DQ11: U101.T20, U201.H7
/MPU_DDR3L_Memory/DDR_DQ12: U101.V20, U201.F7
/MPU_DDR3L_Memory/DDR_DQ13: U101.R20, U201.H3
/MPU_DDR3L_Memory/DDR_DQ14: U101.U21, U201.H8
/MPU_DDR3L_Memory/DDR_DQ15: U101.V21, U201.F8
/MPU_DDR3L_Memory/DDR_DQM0: U101.G20, U201.D3
/MPU_DDR3L_Memory/DDR_DQM1: U101.T21, U201.E7
/MPU_DDR3L_Memory/DDR_DQS0_N: U101.G21, U201.B7
/MPU_DDR3L_Memory/DDR_DQS0_P: U101.G22, U201.C7
/MPU_DDR3L_Memory/DDR_DQS1_N: U101.R22, U201.G3
/MPU_DDR3L_Memory/DDR_DQS1_P: U101.T22, U201.F3
/MPU_DDR3L_Memory/DDR_ODT: R224.2, U101.L21, U201.K1
/MPU_DDR3L_Memory/DDR_RASN: R223.2, U101.M20, U201.J3
/MPU_DDR3L_Memory/DDR_RESETN: R221.2, U101.F19, U201.T2
/MPU_DDR3L_Memory/DDR_WEN: R229.2, U101.M21, U201.L3
ANA0: U101.R4, U703.84
ANA1: U101.T5, U703.83
BOOT0: U101.N3, U703.32
BOOT1: U101.N4, U703.33
BOOT2: U101.P4, U703.34
BT_DEV_WAKE: U101.H3, U601.29
BT_HOST_WAKE: U101.A2, U601.5
BT_PCM_CLK: U101.G2, U601.85
BT_PCM_SDI: U101.H5, U601.82
BT_PCM_SDO: U101.K5, U601.84
BT_PCM_WS: U101.F4, U601.83
BT_REG_ON: U101.G3, U601.9
BT_RF_OUT: C602.1, R601.2, U601.49
BT_USART3_CTS: U101.W1, U601.33
BT_USART3_RTS: U101.W12, U601.34
BT_USART3_RX: U101.AA7, U601.31
BT_USART3_TX: U101.V9, U601.32
DSI_CK_N: U101.A16, U703.95
DSI_CK_P: U101.B16, U703.96
DSI_D0_N: U101.A15, U703.99
DSI_D0_P: U101.B15, U703.100
DSI_D1_N: U101.A17, U703.97
DSI_D1_P: U101.B17, U703.98
GND: C101.2, C102.1, C103.1, C104.2, C105.2, C201.2, C202.2, C203.2, C205.2, C206.2, C207.2, C208.2, C209.2, C210.2, C211.2, C212.2, C213.2, C214.2, C215.2, C216.2, C217.2, C218.2, C220.2, C221.2, C223.2, C224.2, C225.2, C226.2, C227.2, C228.2, C229.2, C230.2, C301.2, C302.2, C303.2, C304.2, C305.2, C306.2, C307.2, C308.2, C309.2, C310.2, C311.2, C312.2, C313.2, C314.2, C315.2, C316.2, C317.2, C321.2, C322.2, C323.2, C324.2, C325.1, C326.2, C327.2, C328.2, C329.2, C330.2, C331.2, C332.2, C333.2, C334.2, C335.2, C336.2, C337.2, C338.2, C339.2, C340.2, C342.2, C401.2, C402.2, C403.2, C404.2, C405.2, C406.2, C407.2, C408.2, C409.1, C410.2, C411.1, C412.1, C413.1, C414.1, C415.1, C416.1, C417.1, C418.2, C419.2, C420.2, C421.2, C501.2, C502.2, C503.2, C504.2, C505.2, C506.2, C507.2, C508.2, C601.2, C602.2, C603.2, C604.2, C605.2, C606.2, C607.2, C608.2, C609.2, H701.1, H702.1, J601.2, J601.3, J602.2, J602.3, R101.2, R201.2, R210.2, R221.1, R222.1, U101.A1, U101.A19, U101.A22, U101.AA4, U101.AA12, U101.AA13, U101.AA16, U101.AA18, U101.AB1, U101.AB18, U101.AB22, U101.B2, U101.B19, U101.C3, U101.C8, U101.C11, U101.C14, U101.C15, U101.C16, U101.C17, U101.C18, U101.C19, U101.C20, U101.D4, U101.D19, U101.E5, U101.E19, U101.F6, U101.F7, U101.F8, U101.F16, U101.F20, U101.G4, U101.G6, U101.G8, U101.G10, U101.G12, U101.G14, U101.G17, U101.H7, U101.J9, U101.J11, U101.J13, U101.J17, U101.J20, U101.K3, U101.K7, U101.K10, U101.K12, U101.K14, U101.L9, U101.L11, U101.L13, U101.L17, U101.L19, U101.L20, U101.M5, U101.M7, U101.M10, U101.M12, U101.M14, U101.N6, U101.N9, U101.N11, U101.N13, U101.N17, U101.P2, U101.P3, U101.P5, U101.P7, U101.P10, U101.P12, U101.P14, U101.P20, U101.R6, U101.R8, U101.R17, U101.T6, U101.T7, U101.T9, U101.T11, U101.T19, U101.U6, U101.U7, U101.U13, U101.U15, U101.U17, U101.U20, U101.V5, U101.V16, U101.V18, U101.V19, U101.W17, U101.W19, U101.Y3, U101.Y7, U101.Y10, U101.Y13, U101.Y14, U101.Y15, U101.Y18, U101.Y20, U201.A9, U201.B1, U201.B3, U201.B9, U201.D1, U201.D8, U201.E1, U201.E2, U201.E8, U201.F9, U201.G1, U201.G8, U201.G9, U201.J2, U201.J8, U201.M1, U201.M9, U201.P1, U201.P9, U201.T1, U201.T9, U401.6, U401.10, U401.15, U401.26, U401.30, U401.32, U401.41, U401.ep, U501.A6, U501.C4, U501.D3, U501.E2, U501.E7, U501.F1, U501.G5, U501.H10, U501.J5, U501.K8, U501.N2, U501.N5, U501.P1, U501.P4, U501.P6, U601.1, U601.2, U601.3, U601.6, U601.11, U601.15, U601.19, U601.20, U601.27, U601.30, U601.36, U601.47, U601.48, U601.50, U601.51, U601.52, U601.53, U601.57, U601.59, U601.60, U601.65, U601.72, U601.73, U601.94, U601.95, U601.96, U601.97, U601.98, U601.99, U601.100, U601.101, U601.102, U601.103, U601.104, U601.105, U601.106, U702.33, U702.34, U702.39, U702.40, U702.57, U702.58, U702.63, U702.64, U702.69, U702.70, U702.75, U702.76, U702.81, U702.82, U702.87, U702.88, U702.93, U702.94, U702.99, U702.100, X101.2, Y101.2, Y101.4
I2C4_SCL: R104.1, U101.G1, U401.4, U703.86
I2C4_SDA: R105.1, U101.H4, U401.3, U703.85
JTDI: U101.D16, U701.43
JTDO_TRACESWO: U101.E16, U701.42
JTRST: U101.E15, U701.41
LPO_32: U101.AB10, U601.80
MPU_VDDA_1V8_REG: C335.1, C336.1, U101.AB12, U101.B14
NRST: C101.1, R106.1, U101.R2, U401.1, U501.J1, U501.J2, U501.J3, U501.K5, U703.82
unnamed: C105.1, U101.R1
unnamed: C317.1, R301.1, R302.1, U101.M4
unnamed: C330.1, U101.AB17
unnamed: C342.1, U101.A18, U101.B18
unnamed: C409.2, U401.34
unnamed: C410.1, U401.40
unnamed: C508.1, U501.C1, U501.C2
unnamed: C603.1, J601.1, R601.1
unnamed: C604.1, R602.2, U601.58
unnamed: C605.1, J602.1, R602.1
unnamed: L401.1, U401.7
unnamed: L402.1, U401.11
unnamed: L403.1, U401.29
unnamed: L404.1, U401.25
unnamed: R101.1, U101.AA17
unnamed: R201.1, U201.L8
unnamed: R210.1, U101.K22
unnamed: R401.1, U401.33
unnamed: R402.1, U401.37
OTG_VBUS: U101.V15, U701.24
PA0_WAKEUP: U101.AA3, U401.43
PA1: U101.V4, U701.1
PA2: U101.AB2, U701.2
PA3: U101.T4, U701.3
PA4: U101.V6, U701.4
PA5: U101.U5, U701.5
PA6: U101.W9, U701.6
PA7: U101.Y9, U701.7
PA10: U101.Y17, U701.8
PA11: U101.Y16, U701.9
PA12: U101.W16, U701.10
PA13: U101.W3, U701.11
PA14: U101.R3, U701.12
PA15: U101.E11, U701.13
PB0: U101.AB5, U701.14
PB1: U101.AA5, U701.15
PB2: U101.V13, U701.16
PB5: U101.AA8, U701.17
PB6: U101.W13, U701.18
PB7: U101.F11, U701.19
PB8: U101.AB8, U701.20
PB9: U101.F12, U701.21
PB11: U101.Y5, U701.22
PB13: U101.V10, U701.23
PC0: U101.U10, U701.70
PC1: U101.AB3, U701.69
PC2: U101.Y1, U701.68
PC3: U101.U3, U701.67
PC4: U101.AB6, U701.66
PC5: U101.AA6, U701.65
PC6: U101.E13, U701.64
PC7: U101.D13, U701.63
PD0: U101.C10, U701.57
PD1: U101.B10, U701.56
PD4: U101.C9, U701.54
PD5: U101.A9, U701.53
PD6: U101.L3, U701.52
PD8: U101.M1, U701.51
PD9: U101.M2, U701.50
PD10: U101.A8, U701.49
PD11: U101.AB9, U701.48
PD13: U101.V14, U701.47
PD14: U101.M3, U701.46
PE0: U101.C5, U702.1
PE1: U101.D7, U702.2
PE2: U101.Y2, U702.3
PE4: U101.F15, U702.4
PE6: U101.E9, U702.5
PE7: U101.W10, U702.6
PE8: U101.Y12, U702.7
PE9: U101.W11, U702.8
PE10: U101.W14, U702.9
PE11: U101.D5, U702.10
PE12: U101.E4, U702.11
PE13: U101.A4, U702.12
PE14: U101.B4, U702.13
PE15: U101.C4, U702.14
PF2: U101.F13, U702.15
PF3: U101.V3, U702.16
PF6: U101.AA11, U702.17
PF7: U101.AA10, U702.18
PF9: U101.AB11, U702.19
PF10: U101.V12, U702.20
PF11: U101.W8, U702.21
PF12: U101.V8, U702.22
PF13: U101.W7, U702.23
PF14: U101.V7, U702.24
PF15: U101.W6, U702.25
PG0: U101.W5, U703.80
PG1: U101.Y4, U703.70
PG2: U101.W4, U703.79
PG3: U101.U4, U703.69
PG4: U101.AB4, U703.78
PG5: U101.U8, U703.68
PG7: U101.Y11, U703.77
PG8: U101.Y8, U703.67
PG9: U101.W15, U703.76
PG10: U101.AA9, U703.66
PG11: U101.U11, U703.75
PG12: U101.J4, U703.65
PG13: U101.AA1, U703.74
PG14: U101.AA2, U703.64
PH2: U101.AB7, U703.73
PH3: U101.Y6, U703.56
PH6: U101.V11, U703.72
PH7: U101.W2, U703.63
PH8: U101.D6, U703.71
PH9: U101.E6, U703.55
PH10: U101.B1, U703.62
PH11: U101.B3, U703.61
PH12: U101.F5, U703.60
PH13: U101.D3, U703.59
PH14: U101.C2, U703.58
PH15: U101.C1, U703.57
PI0: U101.D1, U703.1
PI1: U101.E2, U703.2
PI2: U101.E1, U703.3
PI3: U101.E3, U703.4
PI4: U101.J6, U703.5
PI5: U101.F2, U703.6
PI6: U101.G5, U703.7
PI7: U101.F1, U703.8
PI8: U101.N1, U703.9
PI9: U101.J5, U703.10
PI11: U101.T3, U703.11
PI12: U101.H2, U703.12
PI13: U101.H1, U703.13
PI14: U101.D2, U703.14
PI15: U101.F3, U703.15
PJ0: U101.J2, U703.16
PJ1: U101.L6, U703.17
PJ2: U101.K4, U703.18
PJ3: U101.J1, U703.19
PJ4: U101.K2, U703.20
PJ5: U101.K1, U703.21
PJ6: U101.L5, U703.22
PJ7: U101.H6, U703.23
PJ8: U101.L4, U703.24
PJ9: U101.J3, U703.25
PJ10: U101.L2, U703.26
PJ11: U101.K6, U703.27
PJ12: U101.B8, U703.28
PJ13: U101.A7, U703.29
PJ14: U101.B7, U703.30
PJ15: U101.C7, U703.31
PK0: U101.D8, U703.94
PK1: U101.E7, U703.93
PK2: U101.E8, U703.92
PK3: U101.B6, U703.91
PK4: U101.A6, U703.90
PK5: U101.C6, U703.89
PK6: U101.A5, U703.88
PK7: U101.B5, U703.87
PMIC_LDO1_1V8: C413.2, C606.1, C607.1, C608.1, C609.1, R603.1, R604.1, R605.1, R606.1, R607.1, R608.1, U401.23, U601.13, U601.14, U601.35, U702.65, U702.66, U702.67, U702.68
PMIC_LDO2_2V9: C415.2, U401.18, U702.77, U702.78, U702.79, U702.80
PMIC_LDO3_VTT_DDR: C203.1, C205.1, C206.1, C208.1, C209.1, C210.1, C211.1, C225.1, C226.1, C227.1, C228.1, C229.1, C230.1, C412.2, R202.1, R203.1, R204.1, R205.1, R206.1, R207.1, R208.1, R209.1, R211.1, R212.1, R213.1, R214.1, R215.1, R216.1, R217.1, R218.1, R219.1, R220.1, R223.1, R224.1, R225.1, R227.1, R228.1, R229.1, U401.14
PMIC_LDO4_VDD_USB: C337.1, C417.2, U101.AB13, U101.AB16, U401.39
PMIC_LDO5_2V9: C416.2, C501.1, C502.1, C503.1, C504.1, C505.1, C506.1, C507.1, R501.1, R502.1, R503.1, R504.1, R505.1, R506.1, R507.1, R508.1, R509.1, R510.1, U401.20, U501.A9, U501.B8, U501.C6, U501.C7, U501.E6, U501.F5, U501.J10, U501.K9, U501.M4, U501.N4, U501.P3, U501.P5, U702.35, U702.36, U702.37, U702.38
PMIC_LDO6_1V0: C414.2, U401.21, U702.71, U702.72, U702.73, U702.74
PMIC_VOUT1_VDD_CORE: C305.1, C306.1, C307.1, C308.1, C313.1, C314.1, C315.1, C316.1, C321.1, C322.1, C323.1, C324.1, C326.1, C327.1, C328.1, C329.1, C418.1, L401.2, U101.H9, U101.H11, U101.H13, U101.H15, U101.J8, U101.J10, U101.J12, U101.J14, U101.K9, U101.K11, U101.K13, U101.K15, U101.L8, U101.L10, U101.L12, U101.L14, U101.M11, U101.M13, U101.M15, U101.N12, U101.N14, U101.P13, U101.P15, U101.R14, U101.T15, U401.5
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

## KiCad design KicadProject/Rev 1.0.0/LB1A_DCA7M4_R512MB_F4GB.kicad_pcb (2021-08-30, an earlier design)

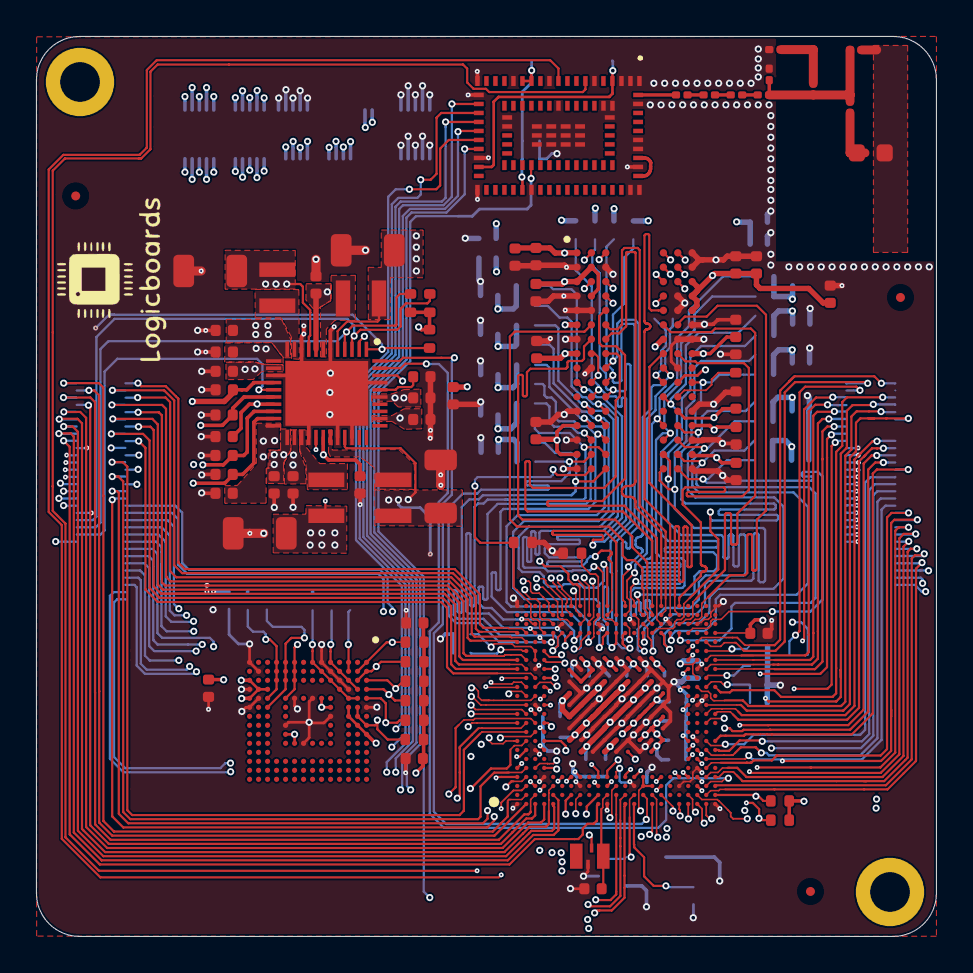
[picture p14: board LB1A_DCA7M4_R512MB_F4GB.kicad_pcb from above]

Board: 6 copper layers, 50.0 x 50.0 mm, 156 parts (0 on the bottom side), 213 nets.

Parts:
C1, C2, C5, C6, C51, C52, C63, C64, C65, C66, C67, C68, C69, C70, C72, C73, C74: 1uF; C_0402_1005Metric
C3, C4, C8, C9, C10, C11, C12, C13, C14, C15, C16, C17, C18, C19, C20, C23, C24, C25, C26, C27, C28, C29, C30, C31, C32, C36, C37, C38, C39, C40, C79, C86: 100nF; C_0402_1005Metric
C7: 10nF; C_0402_1005Metric
C21, C22, C34, C35, C41, C43, C44, C45, C46, C54: 10uF; C_0402_1005Metric
C33: 0.3pF; C_0603_1608Metric
C42: 2.2uF; C_0402_1005Metric
C47, C48, C49, C50: 22uF; C_1206_3216Metric
C53, C55, C56, C57, C58, C59, C60, C61, C62, C85: 4.7uF; C_0402_1005Metric
C71: 0.3pF; C_0201_0603Metric
C75, C76, C77: 10pF; C_0402_1005Metric
C78: 2.0pF; C_0201_0603Metric
FID1, FID2, FID3, FID4, FID5, FID6: Fiducial; Fiducial_0.5mm_Mask1.5mm
H1, H3: MountingHole_Pad; MountingHole_2.2mm_M2_DIN965_Pad
L1, L2, L3, L4: 1uH; MGV2520101R0M-10
L5: 1.0nH; L_0201_0603Metric
L6: 3.0nH; L_0201_0603Metric
L7, L8: 1.5nH; L_0201_0603Metric
R1, R34: 240E; R_0402_1005Metric
R2, R3, R4, R5: 1k5; R_0402_1005Metric
R6, R27, R35, R46: 10k; R_0402_1005Metric
R7: 3k; R_0402_1005Metric
R8, R9, R10, R11, R12, R13, R14, R15, R16, R17, R18, R19, R20, R21, R22, R23, R24, R25, R28, R29, R30, R31, R32, R33: 56E; R_0402_1005Metric
R26: 100E; R_0402_1005Metric
R36, R37, R38, R39, R40, R41, R42, R43, R44, R45: 47k; R_0402_1005Metric
R47, R48, R49: 0E; R_0201_0603Metric
U1: TFBGA361_12X12; STM32MP157CAC3
U2: AS4C256M16D3LC-12BCN
U3: S40FC004C1B2C00000
U4: STPMIC1BPQR
U5, U6, U7: DF40C-70DP-0.4V(51); DF40C70DP04V51
U8: LBEE59B1LV-278; LBEE59B1LV278
X1: 32.768kHz; SiT1533AC-H5-DCC-32.768E
X2: 24MHz; TSX3225240000MF10ZC3

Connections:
5V_VIN: C43.1, C44.1, C45.1, C46.1, C51.1, C52.1, C53.1, U4.8, U4.12, U4.19, U4.22, U4.24, U4.28, U4.36, U6.2, U6.4, U6.6, U6.8, U6.10
ANA0: U1.U3, U7.31
ANA1: U1.U4, U7.33
ANT0: R49.1, U8.58
BOOT0: U1.N1, U5.37
BOOT1: U1.N4, U5.25
BOOT2: U1.M2, U5.41
BT_RF_IN: U8.49, U8.51
DDR_A0: R8.2, U1.L20, U2.N3
DDR_A1: R9.2, U1.P22, U2.P7
DDR_A2: R10.2, U1.J20, U2.P3
DDR_A3: R11.2, U1.K22, U2.N2
DDR_A4: R12.2, U1.V20, U2.P8
DDR_A5: R13.2, U1.H20, U2.P2
DDR_A6: R14.2, U1.W20, U2.R8
DDR_A7: R15.2, U1.E20, U2.R2
DDR_A8: R16.2, U1.Y20, U2.T8
DDR_A9: R17.2, U1.G20, U2.R3
DDR_A10: R18.2, U1.R22, U2.L7
DDR_A11: R19.2, U1.R20, U2.R7
DDR_A12: R20.2, U1.P23, U2.N7
DDR_A13: R21.2, U1.F20, U2.T3
DDR_A14: R22.2, U1.R21, U2.T7
DDR_BA0: R23.2, U1.L23, U2.M2
DDR_BA1: R24.2, U1.U20, U2.N8
DDR_BA2: R25.2, U1.M21, U2.M3
DDR_CASN: R33.2, U1.N20, U2.K3
DDR_CKE: R28.1, R35.2, U1.T20, U2.K9
DDR_CLK_N: R26.1, U1.N23, U2.K7
DDR_CLK_P: R26.2, U1.N22, U2.J7
DDR_CSN: R30.1, U1.M22, U2.L2
DDR_DQ0: U1.E22, U2.A2
DDR_DQ1: U1.F22, U2.C3
DDR_DQ2: U1.H21, U2.A7
DDR_DQ3: U1.E21, U2.C2
DDR_DQ4: U1.J21, U2.B8
DDR_DQ5: U1.J22, U2.C8
DDR_DQ6: U1.H22, U2.D7
DDR_DQ7: U1.G21, U2.A3
DDR_DQ8: U1.T21, U2.F2
DDR_DQ9: U1.U21, U2.E3
DDR_DQ10: U1.T22, U2.G2
DDR_DQ11: U1.W21, U2.F7
DDR_DQ12: U1.W23, U2.H8
DDR_DQ13: U1.T23, U2.H3
DDR_DQ14: U1.W22, U2.H7
DDR_DQ15: U1.Y21, U2.F8
DDR_DQM0: U1.H23, U2.D3
DDR_DQM1: U1.V22, U2.E7
DDR_DQS0_N: U1.G23, U2.B7
DDR_DQS0_P: U1.G22, U2.C7
DDR_DQS1_N: U1.U23, U2.G3
DDR_DQS1_P: U1.U22, U2.F3
DDR_ODT: R31.2, U1.L22, U2.K1
DDR_RASN: R29.2, U1.N21, U2.J3
DDR_RESETN: R27.2, U1.D20, U2.T2
DDR_WEN: R32.1, U1.M20, U2.L3
DSI_BL_CTRL: U1.AA19, U7.70
DSI_CKN: U1.A16, U5.56
DSI_CKP: U1.B16, U5.58
DSI_D0_N: U1.B15, U5.18
DSI_D0_P: U1.C15, U5.54
DSI_D1_N: U1.A17, U5.60
DSI_D1_P: U1.B17, U5.62
DSI_LCD_INT: U1.A14, U5.14
DSI_RESET: U1.D19, U5.36
DSI_TE: U1.B14, U5.16
ETH_CLK: U1.Y8, U7.48
ETH_CLK125: U1.Y6, U7.32
ETH_GTX_CLK: U1.AB2, U7.20
ETH_MDC: U1.AA6, U7.28
ETH_MDINT: U1.AC8, U7.46
ETH_MDIO: U1.AC3, U7.22
ETH_NRST: R6.1, U1.AC2, U7.18
ETH_RXD0: U1.AC7, U7.42
ETH_RXD1: U1.AB7, U7.38
ETH_RXD2: U1.AB6, U7.36
ETH_RXD3: U1.W4, U7.51
ETH_RX_CLK: U1.AA4, U7.16
ETH_RX_DV: U1.AB8, U7.44
ETH_TXD0: U1.AA2, U7.49
ETH_TXD1: U1.AA1, U7.43
ETH_TXD2: U1.Y2, U7.41
ETH_TXD3: U1.Y1, U7.39
ETH_TX_EN: U1.AB1, U7.45
GND: C1.2, C2.2, C3.2, C4.2, C5.1, C6.2, C7.2, C8.2, C9.2, C10.2, C11.2, C12.2, C13.2, C14.2, C15.2, C16.2, C17.2, C18.2, C19.2, C20.2, C21.2, C22.2, C23.2, C24.2, C25.2, C26.2, C27.2, C28.2, C29.2, C30.2, C31.2, C32.1, C34.2, C35.2, C36.2, C37.2, C38.2, C39.2, C40.2, C41.2, C42.2, C43.2, C44.2, C45.2, C46.2, C47.2, C48.2, C49.2, C50.2, C51.2, C52.2, C53.2, C54.2, C55.2, C56.2, C57.2, C58.2, C59.2, C60.2, C61.2, C62.2, C63.2, C64.2, C65.2, C66.2, C67.2, C68.2, C69.2, C70.2, C72.2, C73.2, C74.2, C75.1, C76.1, C77.1, C79.1, C85.2, C86.1, L8.2, R1.2, R7.2, R27.1, R34.2, R35.1, R47.1, U1.1A3, U1.1A5, U1.1A7, U1.1B2, U1.1B4, U1.1B6, U1.1B8, U1.1C1, U1.1C3, U1.1C5, U1.1C7, U1.1C9, U1.1D2, U1.1D4, U1.1D6, U1.1D8, U1.1E1, U1.1E3, U1.1E5, U1.1E7, U1.1E9, U1.1F2, U1.1F4, U1.1F6, U1.1F8, U1.1G1, U1.1G3, U1.1G5, U1.1G7, U1.1G9, U1.1H2, U1.1H4, U1.1H6, U1.1H8, U1.1J3, U1.1J5, U1.1J7, U1.A1, U1.A23, U1.AA5, U1.AA8, U1.AA12, U1.AA16, U1.AA21, U1.AB13, U1.AC1, U1.AC23, U1.C7, U1.C12, U1.C16, U1.C21, U1.D4, U1.F21, U1.H3, U1.K21, U1.L1, U1.P3, U1.P21, U1.V21, U1.W3, U2.A9, U2.B1, U2.B3, U2.B9, U2.D1, U2.D8, U2.E1, U2.E2, U2.E8, U2.F9, U2.G1, U2.G8, U2.G9, U2.J2, U2.J8, U2.M1, U2.M9, U2.P1, U2.P9, U2.T1, U2.T9, U3.A6, U3.C4, U3.D3, U3.E2, U3.E7, U3.F1, U3.G5, U3.H10, U3.J5, U3.K8, U3.N2, U3.N5, U3.P1, U3.P4, U3.P6, U4.6, U4.10, U4.15, U4.26, U4.30, U4.32, U4.41, U4.ep, U6.27, U6.29, U6.31, U6.33, U6.35, U6.61, U6.62, U6.63, U6.64, U6.65, U6.66, U6.67, U6.68, U6.69, U6.70, U8.1, U8.2, U8.3, U8.6, U8.11, U8.15, U8.19, U8.20, U8.27, U8.30, U8.36, U8.47, U8.48, U8.50, U8.52, U8.53, U8.57, U8.59, U8.60, U8.65, U8.72, U8.73, U8.94, U8.95, U8.96, U8.97, U8.98, U8.99, U8.100, U8.101, U8.102, U8.103, U8.104, U8.105, U8.106, X1.2, X2.2, X2.4
HDMI_CEC: U1.Y14, U7.53
HDMI_INT: U1.W1, U7.37
HDMI_NRST: U1.Y17, U7.65
I2C1_SCL: R2.1, U1.Y18, U7.67
I2C1_SDA: R3.1, U1.Y4, U7.47
I2C4_SCL: R4.1, U1.G2, U4.4, U5.29
I2C4_SDA: R5.1, U1.H2, U4.3, U5.31
I2S2_CK: U1.D14, U5.24
I2S2_SDO: U1.E1, U5.57
I2S2_WS: U1.B10, U5.50
JTCK_SWCLK: U1.B20, U5.70
JTDI: U1.A20, U5.68
JTDO_TRACESWO: U1.A19, U5.64
JTMS_SWDIO: U1.C20, U5.34
LCD_B0: U1.K1, U5.53
LCD_B1: U1.K4, U5.45
LCD_B2: U1.AB11, U7.54
LCD_B3: U1.B5, U5.44
LCD_B4: U1.B4, U5.42
LCD_B5: U1.U2, U7.35
LCD_B6: U1.F4, U5.51
LCD_B7: U1.K3, U5.43
LCD_CLK: U1.AC14, U7.66
LCD_DE: U1.Y12, U7.50
LCD_G0: U1.AA7, U7.30
LCD_G1: U1.C10, U5.52
LCD_G2: U1.D1, U5.61
LCD_G3: U1.C3, U5.40
LCD_G4: U1.B1, U5.67
LCD_G5: U1.C1, U5.63
LCD_G6: U1.E3, U5.59
LCD_G7: U1.E2, U5.55
LCD_HSYNC: U1.T1, U7.27
LCD_R0: U1.AB4, U7.26
LCD_R1: U1.AA3, U7.14
LCD_R2: U1.D5, U5.12
LCD_R3: U1.C5, U5.10
LCD_R4: U1.C2, U5.65
LCD_R5: U1.AB5, U7.34
LCD_R6: U1.B2, U5.69
LCD_R7: U1.D3, U5.38
LCD_VSYNC: U1.H4, U5.47
LPO_32: U1.L4, U8.80
MPU_VDDA_1V8_REG: C1.1, C4.1, U1.AB14, U1.C14
NJRST: U1.B19, U5.66
NRST: R46.2, U1.M3, U3.J1, U3.J2, U3.J3, U3.K5, U4.1, U5.33
unnamed: C5.2, U1.C17, U1.C18
unnamed: C6.1, U1.AB15
unnamed: C7.1, U1.M4
unnamed: C33.1, L5.2
unnamed: C33.2, C71.2
unnamed: C42.1, U3.C1, U3.C2
unnamed: C62.1, U4.40
unnamed: C71.1, C78.1, L5.1, L6.2, L8.1
unnamed: C75.2, U1.P2, X2.3
unnamed: C76.2, U1.P1, X2.1
unnamed: C77.2, U1.L2, X1.3
unnamed: C78.2, L7.1
unnamed: L1.1, U4.7
unnamed: L2.1, U4.11
unnamed: L3.1, U4.29
unnamed: L4.1, U4.25
unnamed: L6.1, R47.2
unnamed: L7.2, R48.2
unnamed: R1.1, U1.K23
unnamed: R7.1, U1.AB18
unnamed: R34.1, U2.L8
unnamed: R48.1, R49.2
PA0_WKUP: U1.AB3, U4.43
PMIC_LDO1_1V8: C56.1, C79.2, C85.1, C86.2, U4.23, U6.16, U6.18, U6.20, U6.22, U6.24, U8.13, U8.14, U8.35
PMIC_LDO2_2V9: C57.1, U4.18, U6.30, U6.32, U6.34, U6.36
PMIC_LDO3_VTT_DDR: C9.1, C10.1, C11.1, C12.1, C13.1, C14.1, C15.1, C16.1, C17.1, C18.1, C19.1, C20.1, C21.1, C22.1, C58.1, R8.1, R9.1, R10.1, R11.1, R12.1, R13.1, R14.1, R15.1, R16.1, R17.1, R18.1, R19.1, R20.1, R21.1, R22.1, R23.1, R24.1, R25.1, R28.2, R29.1, R30.2, R31.1, R32.2, R33.1, U4.14
PMIC_LDO4_VDD_USB: C3.1, C59.1, U1.AA15, U1.AA17, U4.39
PMIC_LDO5_2V9: C38.1, C39.1, C40.1, C41.1, C60.1, R36.1, R37.1, R38.1, R39.1, R40.1, R41.1, R42.1, R43.1, R44.1, R45.1, U3.A9, U3.B8, U3.C6, U3.C7, U3.E6, U3.F5, U3.J10, U3.K9, U3.M4, U3.N4, U3.P3, U3.P5, U4.20, U6.51, U6.53
PMIC_LDO6_1V0: C61.1, U4.21, U6.42, U6.44, U6.46, U6.48
PMIC_VOUT1_VDD_CORE: C47.1, C63.1, C64.1, C65.1, C66.1, L1.2, U1.1A2, U1.1A4, U1.1A6, U1.1B1, U1.1B3, U1.1B5, U1.1C2, U1.1C4, U1.1C6, U1.1D1, U1.1D3, U1.1D5, U1.1D7, U1.1E2, U1.1E4, U1.1E6, U1.1F5, U1.1F7, U1.1G6, U1.1H7, U4.5
PMIC_VOUT2_VDD_DDR: C23.1, C24.1, C25.1, C26.1, C27.1, C28.1, C29.1, C30.1, C31.1, C34.1, C35.1, C48.1, C54.1, C72.1, C73.1, C74.1, L2.2, U1.1A8, U1.1B7, U1.1B9, U1.1C8, U1.1D9, U1.1E8, U1.1F9, U1.1G8, U1.1H9, U1.1J8, U2.A1, U2.A8, U2.B2, U2.C1, U2.C9, U2.D2, U2.D9, U2.E9, U2.F1, U2.G7, U2.H2, U2.H9, U2.K2, U2.K8, U2.N1, U2.N9, U2.R1, U2.R9, U4.9, U4.13
PMIC_VOUT3_VDD: C2.1, C49.1, C67.1, C68.1, C69.1, C70.1, L3.2, R2.2, R3.2, R4.2, R5.2, R6.2, R46.1, U1.1F1, U1.1F3, U1.1G2, U1.1G4, U1.1H1, U1.1H3, U1.1H5, U1.1J2, U1.1J4, U1.1J6, U1.B18, U1.R3, U1.R4, U1.T3, U4.31, U4.42, U6.15, U6.17, U6.19, U6.21, U6.23, X1.4
PMIC_VOUT4_3V3: C50.1, L4.2, U4.27, U6.1, U6.3, U6.5, U6.7, U6.9
PMIC_VREF_DDR: C8.1, C36.1, C37.1, C55.1, U1.AC20, U2.H1, U2.M8, U4.16
PMIC_WAKEUP: U1.K2, U4.2
POWER_ON: U1.R2, U4.44
SDMMC1_CK: U1.D13, U5.22
SDMMC1_CMD: U1.D12, U5.20
SDMMC1_D0: U1.D18, U5.32
SDMMC1_D1: U1.D17, U5.30
SDMMC1_D2: U1.D15, U5.26
SDMMC1_D3: U1.D16, U5.28
SDMMC2_CK: R45.2, U1.C9, U3.K1, U3.K2, U3.K3, U3.M6
SDMMC2_CMD: R44.2, U1.A10, U3.L1, U3.L2, U3.L3, U3.M5
SDMMC2_D0: R36.2, U1.C13, U3.A3
SDMMC2_D1: R37.2, U1.B12, U3.A4
SDMMC2_D2: R38.2, U1.A11, U3.A5
SDMMC2_D3: R39.2, U1.B13, U3.A1, U3.B2
SDMMC2_D4: R40.2, U1.AB10, U3.A2, U3.B3
SDMMC2_D5: R41.2, U1.A8, U3.B4, U3.C3, U3.D2, U3.E1
SDMMC2_D6: R42.2, U1.C11, U3.B5, U3.C5, U3.D4, U3.E3, U3.F2, U3.G1
SDMMC2_D7: R43.2, U1.B11, U3.A8, U3.B6, U3.B7
SDMMC3_CK: U1.B7, U8.24
SDMMC3_CMD: U1.A5, U8.26
SDMMC3_D0: U1.D8, U8.23
SDMMC3_D1: U1.D9, U8.22
SDMMC3_D2: U1.D7, U8.21
SDMMC3_D3: U1.D10, U8.25
SPI5_MISO: U1.AC11, U7.52
SPI5_MOSI: U1.AA14, U7.62
SPI5_NSS: U1.AA13, U7.64
SPI5_SCK: U1.AB12, U7.60
STLINK_UART4_RX: U1.B8, U5.46
STLINK_UART4_TX: U1.B9, U5.48
STUSB1600_IRQOUTn: U1.P4, U7.25
USART1_CTS: U1.G4, U5.49
USART1_RTS: U1.AB19, U7.69
USART1_RX: U1.Y16, U7.55
USART1_TX: U1.Y7, U7.40
USB_DM1: U1.AB17, U7.63
USB_DM2: U1.AB16, U7.59
USB_DP1: U1.AC17, U7.61
USB_DP2: U1.AC16, U7.57
U_BUTTON_1: U1.N2, U5.39
U_BUTTON_2: U1.T2, U7.29
U_LED_1: U1.L3, U5.35
U_LED_2: U1.AC4, U7.24
VDDOUT_VDDIO: C32.2, U8.4, U8.28
WL_HOST_WAKE: U1.A4, U8.7
WL_REG_ON: U1.B3, U8.10
nPONKEY: U4.17, U5.27

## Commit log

2021-08-30 Added Rev 4.0.0
    [BOARD_TO_BOARD_CONNECTORS.sch, LB1A_V3.kicad_pcb, LB1A_V3.sch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]
2021-08-30 updated board size to 43x43
    [LB1A_V3.kicad_pcb]
2021-08-30 Cleared all traces for rerouting.
    [LB1A_V3.kicad_pcb]
2021-08-30 updated connectors coutyards
    [LB1A_V3.kicad_pcb]
2021-08-30 working on ground connections
    [LB1A_V3.kicad_pcb, MPU Power.sch]

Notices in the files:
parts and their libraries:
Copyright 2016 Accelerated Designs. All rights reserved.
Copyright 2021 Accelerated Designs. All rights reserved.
